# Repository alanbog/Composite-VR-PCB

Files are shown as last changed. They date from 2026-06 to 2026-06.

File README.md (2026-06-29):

# Composite-VR-PCB

This repository contains the hardware design of a controller board for CRT-based VR headset. The circuit contains an AMD Spartan 7 FPGA which splits the incoming HDMI video into separate luma only (black-and-white) NTSC composite video signals for the left and right eye. It also contains an RP2040 microcontroller which serves two purposes:

1. Act as a JTAG programmer for the FPGA using [xvc-pico](https://github.com/kholia/xvc-pico)
2. Transmit 3-DOF tracking data back to a PC using the on-board IMU (based on [Relativty](https://github.com/relativty/Relativty)).

The board also contains a USB hub and a USB C port intended to be connected to a Vive Tracker. When a Vive tracker is connected and SteamVR settings are configured to use the Vive Tracker to [override the default tracking](https://github.com/ValveSoftware/openvr/wiki/TrackingOverrides), the onboard IMU  tracking will not be used, and the RP2040 will only serve to let SteamVR know that the headset is connected. 

The board is the same dimensions and has the same mounting hole placement as a Raspberry Pi Zero.

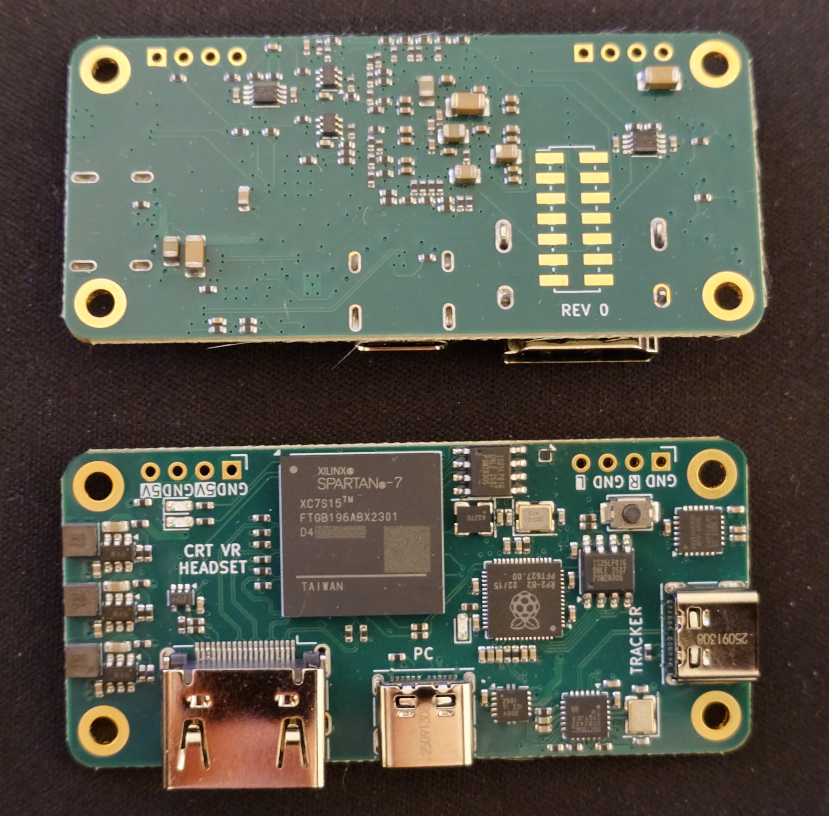
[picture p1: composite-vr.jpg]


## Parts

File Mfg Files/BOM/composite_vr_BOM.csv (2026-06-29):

Reference | Qty | Value | Tolerance | Rating | DNP | Footprint | Mfg | Mfg PN | JLCPCB
C1,C2,C7,C8,C9,C10,C11,C14,C15,C16,C17,C19,C21,C24,C25,C27,C29,C30,C34,C42,C56,C58,C59,C70 | 24 | 100n | 10% | 16V |  | PCM_JLCPCB:C_0402 | Samsung Electro-Mechanics | CL05B104KO5NNNC | C1525
C3,C5,C28,C33 | 4 | 15p | 5% | 50V |  | PCM_JLCPCB:C_0402 | FH (Guangdong Fenghua Advanced Tech) | 0402CG150J500NT | C1548
C4,C13,C20,C67 | 4 | 10u | 10% | 10V |  | PCM_JLCPCB:C_0603 | Samsung Electro-Mechanics | CL10A106KP8NNNC | C19702
C6 | 1 | 2.2n | 10% | 50V |  | PCM_JLCPCB:C_0402 | FH (Guangdong Fenghua Advanced Tech) | 0402B222K500NT | C1531
C12,C18,C26,C36,C39,C43,C44,C49,C51,C52 | 10 | 4u7 | 20% | 10V |  | PCM_JLCPCB:C_0402 | Samsung Electro-Mechanics | CL05A475MP5NRNC | C23733
C22,C23,C31,C32 | 4 | 1u | 10% | 25V |  | PCM_JLCPCB:C_0402 | Samsung Electro-Mechanics | CL05A105KA5NQNC | C52923
C35,C40,C41 | 3 | 100n | 10% | 16V | DNP | PCM_JLCPCB:C_0402 | Samsung Electro-Mechanics | CL05B104KO5NNNC | C1525
C37,C45,C69 | 3 | 100u | 20% | 6.3V |  | PCM_JLCPCB:C_1206 | Samsung Electro-Mechanics | CL31A107MQHNNNE | C15008
C38,C53,C61,C65,C68 | 5 | 47u | 20% | 6.3V |  | PCM_JLCPCB:C_0805 | Samsung Electro-Mechanics | CL21A476MQYNNNE | C16780
C46,C47,C48,C50,C54,C55,C57,C60,C62,C63,C64,C66 | 12 | 470n | 10% | 10V |  | PCM_JLCPCB:C_0402 | Samsung Electro-Mechanics | CL05A474KP5NNNC | C47339
D1,D2,D3 | 3 | Red LED |  |  |  | LED_SMD:LED_0603_1608Metric | Hubei KENTO Elec | KT-0603R | C2286
J1,J2 | 2 | Conn_01x04 |  |  | DNP | Connector_PinHeader_2.54mm:PinHeader_1x04_P2.54mm_Vertical |  |  | -
J3,J5 | 2 | USB_C_Receptacle |  |  |  | Connector_USB:USB_C_Receptacle_Molex_105450-0101 | MOLEX | 1054500101 | C134092
J4 | 1 | HDMI_A |  |  |  | Connector_Video:HDMI_A_Molex_208658-1001_Horizontal | XUNPU | HDMI-001S | C720616
J6 | 1 | Conn_02x07_Odd_Even |  |  | DNP | Connector_PinHeader_2.00mm:PinHeader_2x07_P2.00mm_Vertical_SMD
L1,L2,L3 | 3 | 2u2 |  |  |  | Inductor_SMD:L_Taiyo-Yuden_MD-3030 | Murata Electronics | LQH3NPN2R2MJRL | C341775
R1,R5,R15,R23,R26,R27,R64,R66,R76,R80 | 10 | 0 | 1% | 62.5mW |  | PCM_JLCPCB:R_0402 | UNI-ROYAL(Uniroyal Elec) | 0402WGF0000TCE | C17168
R2,R4,R19,R20,R22 | 5 | 2.2K | 1% | 62.5mW |  | PCM_JLCPCB:R_0402 | UNI-ROYAL(Uniroyal Elec) | 0402WGF2201TCE | C25879
R3,R7,R9,R13,R14,R16,R24,R25 | 8 | 49.9 | 1% | 62.5mW |  | PCM_JLCPCB:R_0402 | UNI-ROYAL(Uniroyal Elec) | 0402WGF499JTCE | C25120
R6,R78 | 2 | 10K | 1% | 62.5mW |  | PCM_JLCPCB:R_0402 | UNI-ROYAL(Uniroyal Elec) | 0402WGF1002TCE | C25744
R8,R12,R21 | 3 | 1K | 1% | 62.5mW |  | PCM_JLCPCB:R_0402 | UNI-ROYAL(Uniroyal Elec) | 0402WGF1001TCE | C11702
R10,R34 | 2 | 33K | 1% | 62.5mW |  | PCM_JLCPCB:R_0402 | UNI-ROYAL(Uniroyal Elec) | 0402WGF3302TCE | C25779
R11,R31,R32,R94 | 4 | 22K | 1% | 62.5mW |  | PCM_JLCPCB:R_0402 | UNI-ROYAL(Uniroyal Elec) | 0402WGF2202TCE | C25768
R17,R33,R35,R36,R37,R100,R101,R102 | 8 | 100K | 1% | 62.5mW |  | PCM_JLCPCB:R_0402 | UNI-ROYAL(Uniroyal Elec) | 0402WGF1003TCE | C25741
R18,R74,R93 | 3 | 200K | 1% | 62.5mW |  | PCM_JLCPCB:R_0402 | UNI-ROYAL(Uniroyal Elec) | 0402WGF2003TCE | C25764
R28,R98 | 2 | 5.1K | 1% | 62.5mW |  | PCM_JLCPCB:R_0402 | UNI-ROYAL(Uniroyal Elec) | 0402WGF5101TCE | C25905
R29,R30 | 2 | 22 | 1% | 62.5mW |  | PCM_JLCPCB:R_0402 | UNI-ROYAL(Uniroyal Elec) | 0402WGF220JTCE | C25092
R38,R39,R40,R41,R51,R58,R62,R72,R81,R83,R89,R90,R91,R92 | 14 | 7.5K | 0.1% | 62.5mW |  | PCM_JLCPCB:R_0402 | UNI-ROYAL(Uniroyal Elec) | TC0225B7501TCC | C28566374
R42,R45,R46,R47,R48,R50,R53,R59,R63,R75,R79,R82,R84,R85,R86,R87,R88,R97 | 18 | 15K | 0.1% | 62.5mW |  | PCM_JLCPCB:R_0402 | FH (Guangdong Fenghua Advanced Tech) | TC02G1502BT | C20627044
R43,R44,R49,R67,R68,R69,R70,R77,R96 | 9 | 4.7K | 1% | 62.5mW |  | PCM_JLCPCB:R_0402 | UNI-ROYAL(Uniroyal Elec) | 0402WGF4701TCE | C25900
R52,R65 | 2 | 75 | 1% | 62.5mW |  | PCM_JLCPCB:R_0402 | UNI-ROYAL(Uniroyal Elec) | 0402WGF750JTCE | C25133
R54,R55 | 2 | 4.7K | 1% | 62.5mW | DNP | PCM_JLCPCB:R_0402 | UNI-ROYAL(Uniroyal Elec) | 0402WGF4701TCE | C25900
R56,R57 | 2 | 75 | 1% | 62.5mW | DNP | PCM_JLCPCB:R_0402 | UNI-ROYAL(Uniroyal Elec) | 0402WGF750JTCE | C25133
R60,R71 | 2 | 8.2K | 1% | 62.5mW |  | PCM_JLCPCB:R_0402 | UNI-ROYAL(Uniroyal Elec) | 0402WGF8201TCE | C25924
R61,R73 | 2 | 18K | 1% | 62.5mW |  | PCM_JLCPCB:R_0402 | UNI-ROYAL(Uniroyal Elec) | 0402WGF1802TCE | C25762
R95 | 1 | 330 | 1% | 62.5mW |  | PCM_JLCPCB:R_0402 | UNI-ROYAL(Uniroyal Elec) | 0402WGF3300TCE | C25104
R99 | 1 | 12K | 1% | 62.5mW |  | PCM_JLCPCB:R_0402 | UNI-ROYAL(Uniroyal Elec) | 0402WGF1202TCE | C25752
SW1 | 1 | SW_Push |  |  |  | Button_Switch_SMD:SW_SPST_TS-1088-xR025 | XUNPU | TS-1088-AR02016 | C720477
U1 | 1 | AK09918C |  |  | DNP | Package_BGA:WLP-4_0.83x0.83mm_P0.4mm | Asahi Kasei Microdevices | AK09918C | C2655004
U2,U6 | 2 | IS25LP016D |  |  |  | Package_SO:SO-8_3.9x4.9mm_P1.27mm | ISSI(Integrated Silicon Solution) | IS25LP016D-JNLE-TR | C2653501
U3 | 1 | xc7s15ftgb196 |  |  |  | Package_BGA:Xilinx_FTGB196 | AMD/XILINX | XC7S15-2FTGB196I | C1521865
U4 | 1 | MPU-6050 |  |  |  | Sensor_Motion:InvenSense_QFN-24_4x4mm_P0.5mm | TDK InvenSense | MPU-6050 | C24112
U5,U9,U10 | 3 | TLV62568PDDCR |  |  |  | Library:SOT-23-6-small_courtyard | Texas Instruments | TLV62568PDDCR | C398369
U7 | 1 | NC7SZ125P5X |  |  |  | Package_TO_SOT_SMD:SOT-353_SC-70-5 | onsemi | NC7SZ125P5X | C112084
U8 | 1 | RP2040 |  |  |  | Package_DFN_QFN:QFN-56-1EP_7x7mm_P0.4mm_EP3.2x3.2mm | Raspberry Pi | RP2040 | C2040
U11 | 1 | TPS2561 |  |  |  | Package_SON:VSON-10-1EP_3x3mm_P0.5mm_EP1.65x2.4mm_ThermalVias | Texas Instruments | TPS2561DRCR | C140303
U12 | 1 | USB2422 |  |  |  | Package_DFN_QFN:QFN-24-1EP_4x4mm_P0.5mm_EP2.5x2.5mm | Microchip Tech | USB2422T/MJ | C622611
U13,U15 | 2 | OPA358 |  |  |  | Package_TO_SOT_SMD:SOT-363_SC-70-6 | Texas Instruments | OPA358AIDCKT | C2057755
U14 | 1 | TXS0102DCU |  |  | DNP | Package_SO:VSSOP-8_2.3x2mm_P0.5mm | Texas Instruments | TXS0102DCUR | C53434
U16 | 1 | TXS0102DCU |  |  |  | Package_SO:VSSOP-8_2.3x2mm_P0.5mm | Texas Instruments | TXS0102DCUR | C53434
Y1 | 1 | 50MHz |  |  |  | Oscillator:Oscillator_SMD_SiT_PQFN-4Pin_3.2x2.5mm | SiTime | SiT8008BI-22-33E-50.000000 | C26267
Y2 | 1 | 12MHz |  |  |  | Crystal:Crystal_SMD_3225-4Pin_3.2x2.5mm | SJK(SHENZHEN CRYSTAL TECH) | 7U12000E09UCG | C524716
Y3 | 1 | 24MHz |  |  |  | Crystal:Crystal_SMD_3225-4Pin_3.2x2.5mm | SJK(SHENZHEN CRYSTAL TECH) | 7U24000E09UCG | C251611

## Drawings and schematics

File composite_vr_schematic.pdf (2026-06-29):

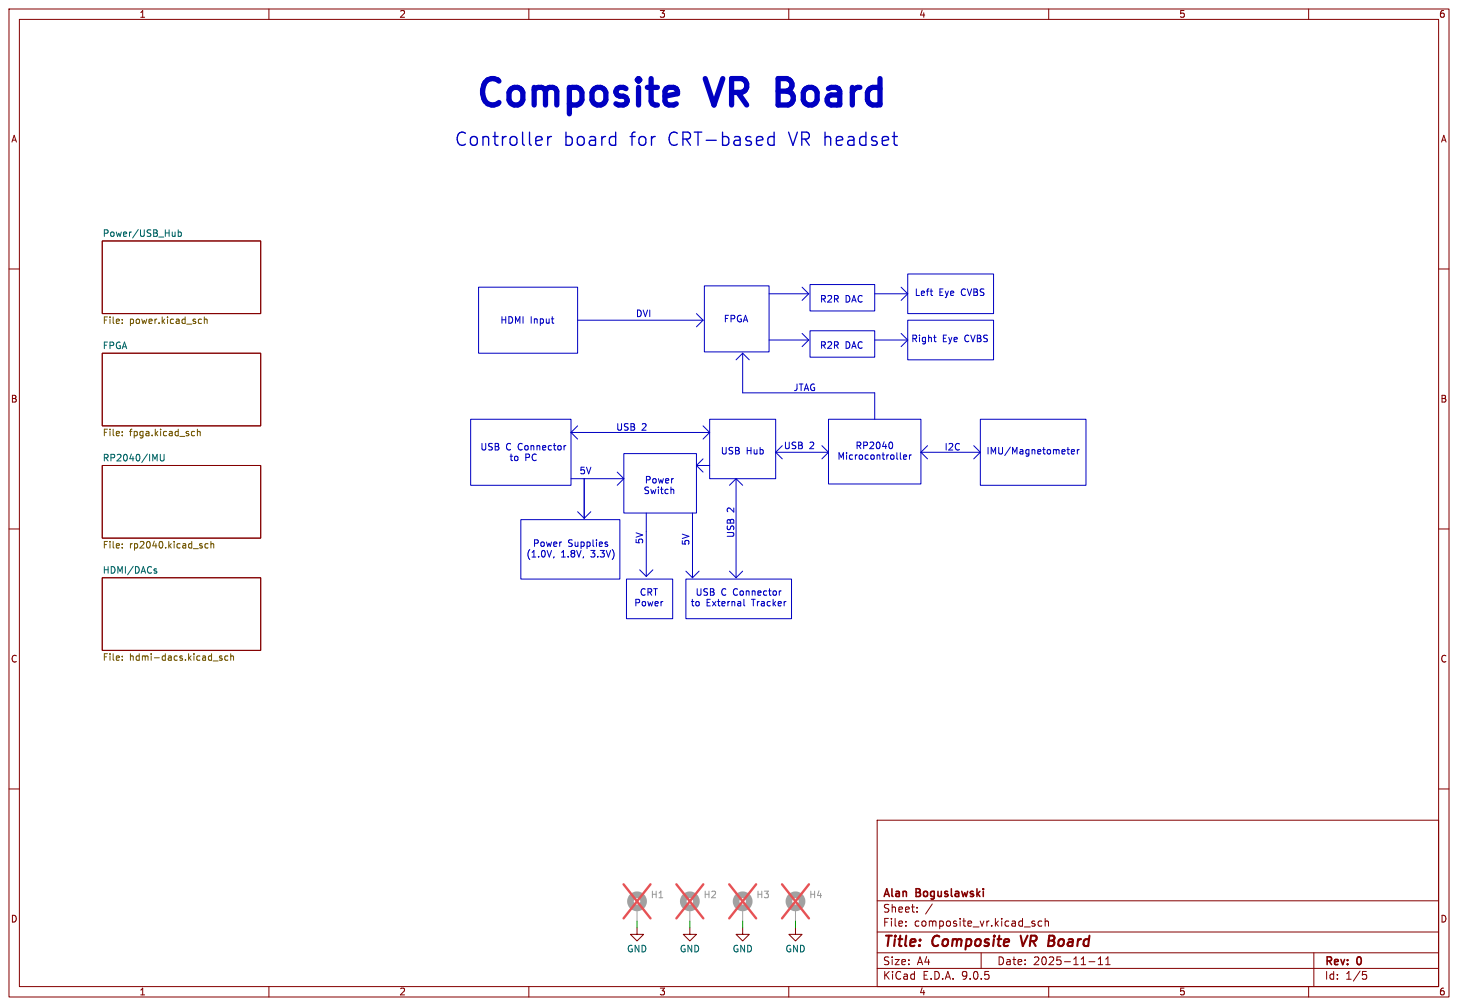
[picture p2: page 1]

Id: 1/5 Title: Composite VR Board

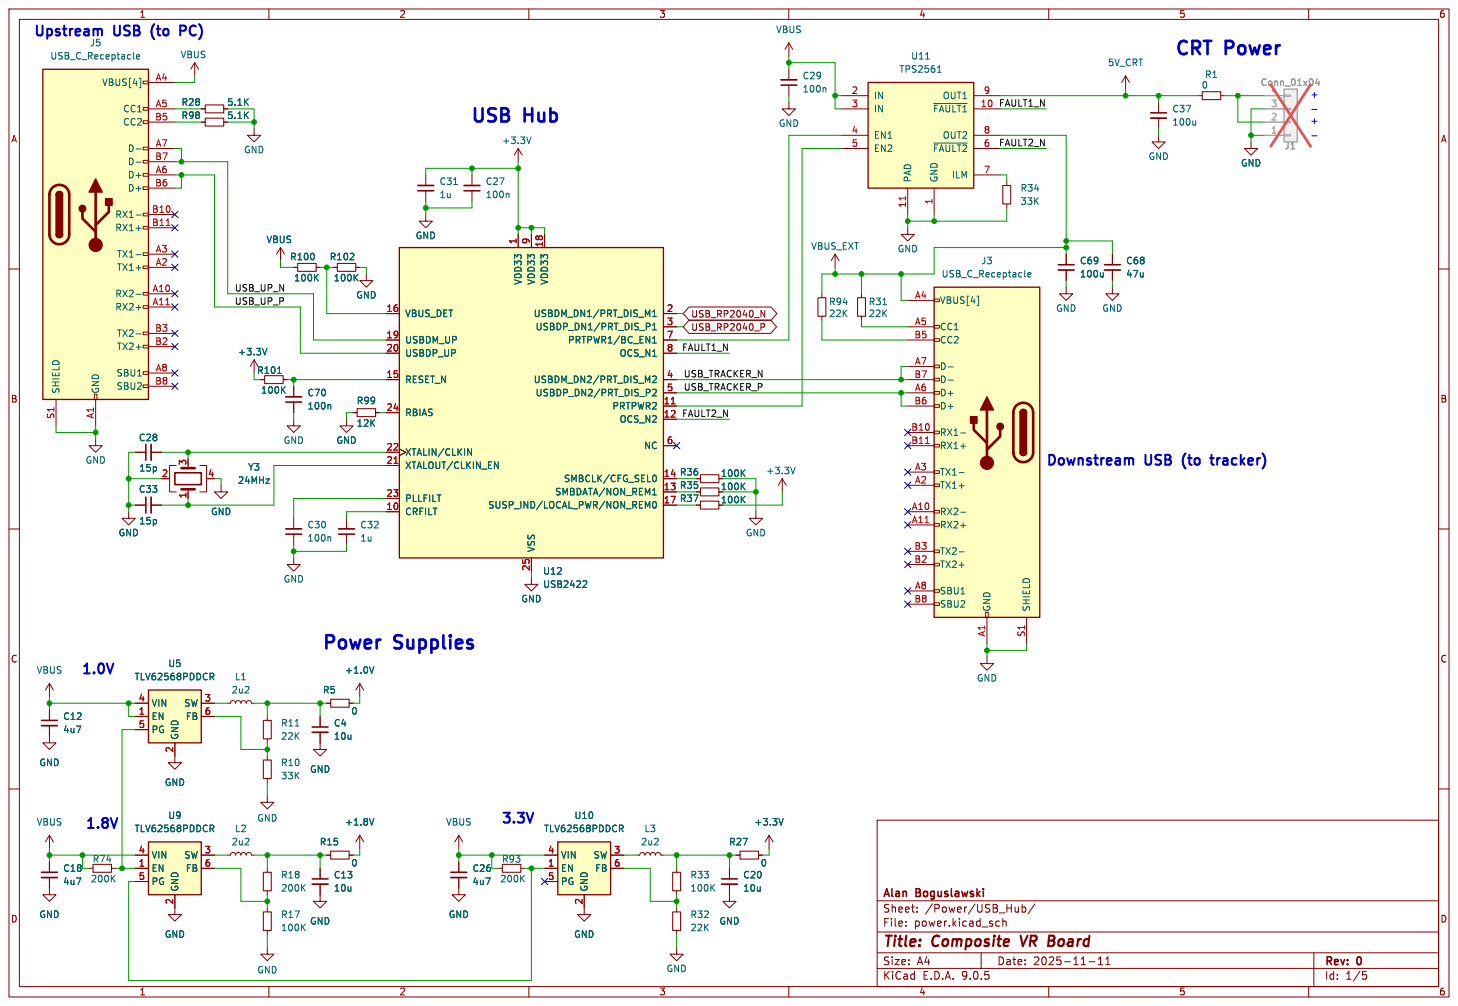
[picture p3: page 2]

Upstream USB (to PC)

9 VSS 25 VDD33 18 USBDM_DN1/PRT_DIS_M1 2 USBDP_DN1/PRT_DIS_P1 3 PRTPWR1/BC_EN1 7 OCS_N1 8 USBDM_DN2/PRT_DIS_M2 4 USBDP_DN2/PRT_DIS_P2 5 PRTPWR2 11 OCS_N2 12 NC 6 SMBCLK/CFG_SEL0 14 SMBDATA/NON_REM1 13 SUSP_IND/LOCAL_PWR/NON_REM0 17 U12 USB2422 C31

9 VSS 25 VDD33 18 USBDM_DN1/PRT_DIS_M1 2 USBDP_DN1/PRT_DIS_P1 3 PRTPWR1/BC_EN1 7 OCS_N1 8 USBDM_DN2/PRT_DIS_M2 4 USBDP_DN2/PRT_DIS_P2 5 PRTPWR2 11 OCS_N2 12 NC 6 SMBCLK/CFG_SEL0 14 SMBDATA/NON_REM1 13 SUSP_IND/LOCAL_PWR/NON_REM0 17 GND

Downstream USB (to tracker)

2 SW 3 FB 6 GND GND

Id: 1/5 Title: Composite VR Board

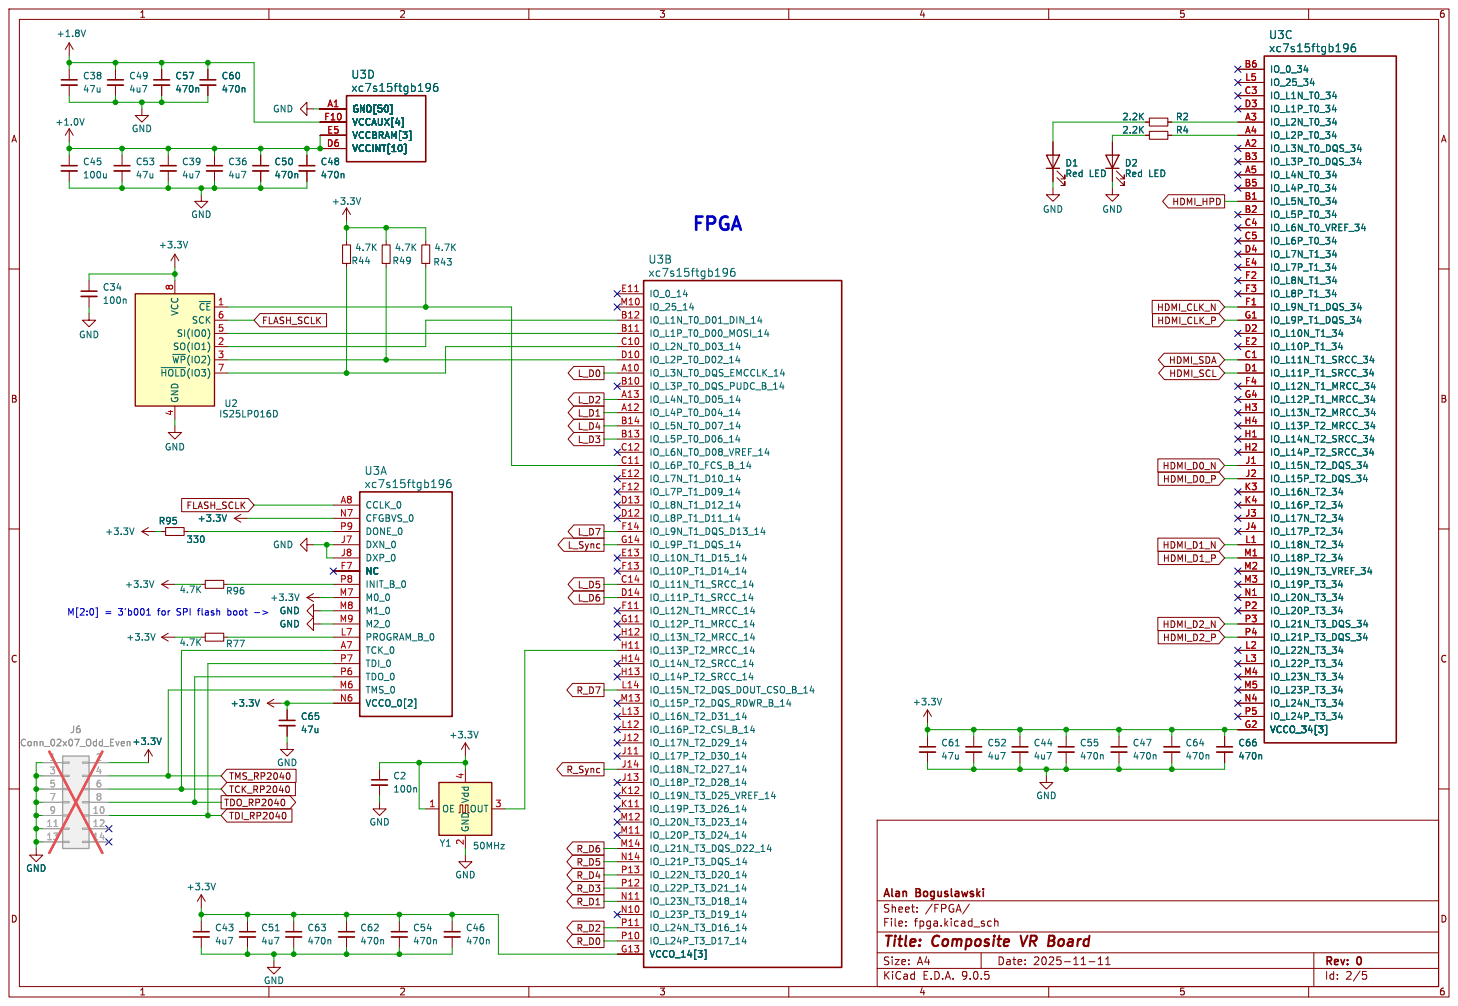
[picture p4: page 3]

8 GND
~{CE}1 SCK 6 SI(IO0) 5 SO(IO1) 2 ~{WP}(IO2)3 ~{HOLD}(IO3)7 VCC

Id: 2/5 Title: Composite VR Board

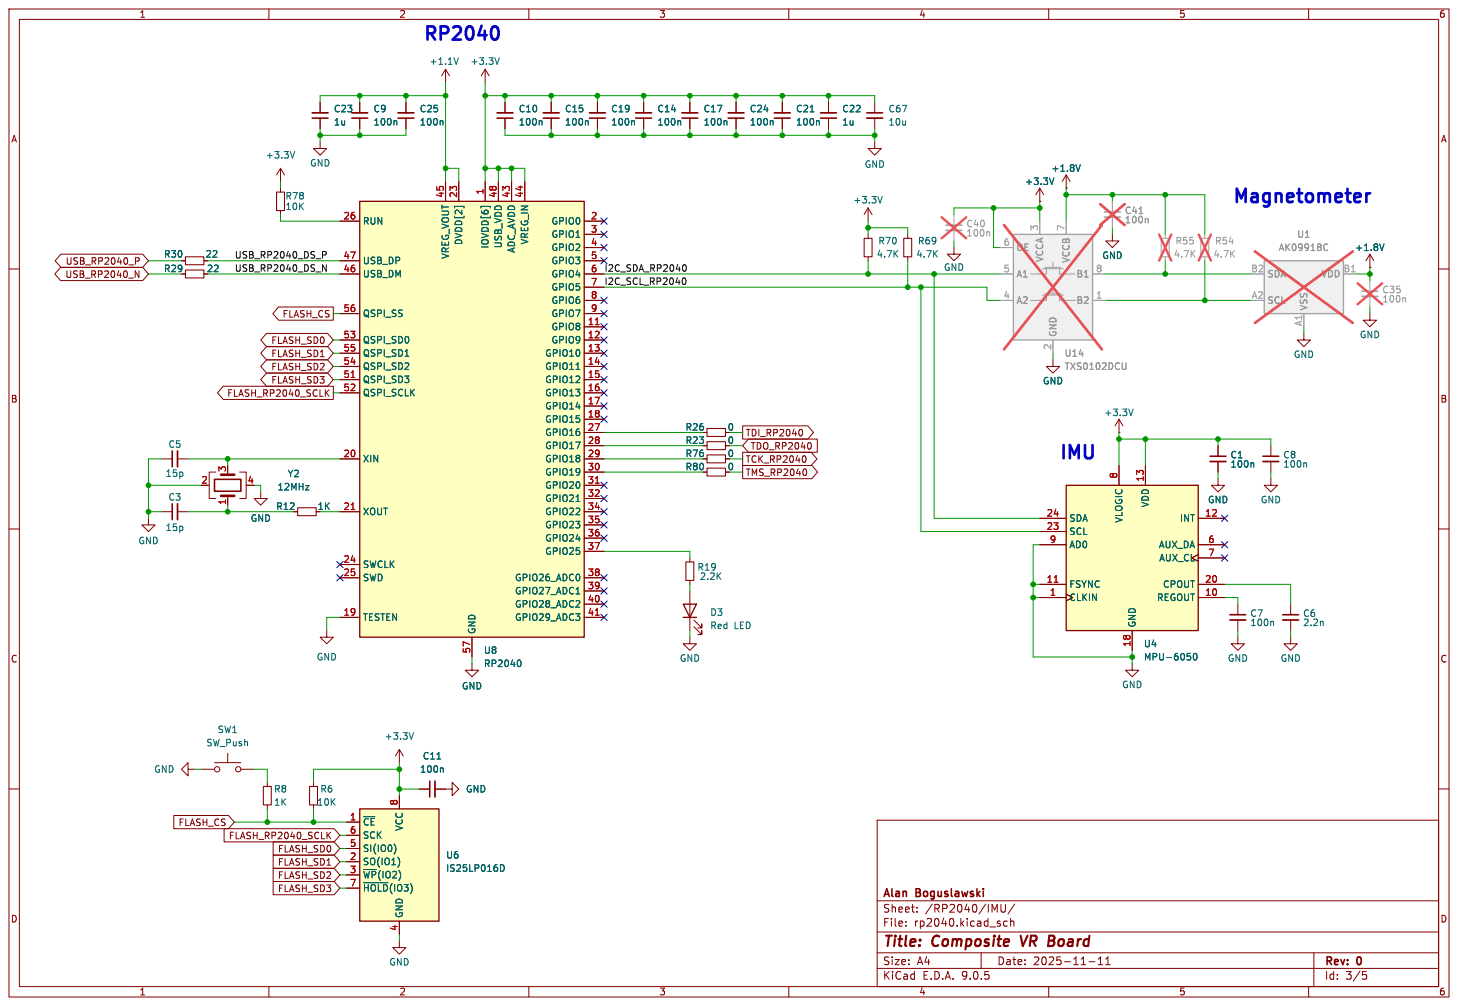
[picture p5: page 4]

Id: 3/5 Title: Composite VR Board

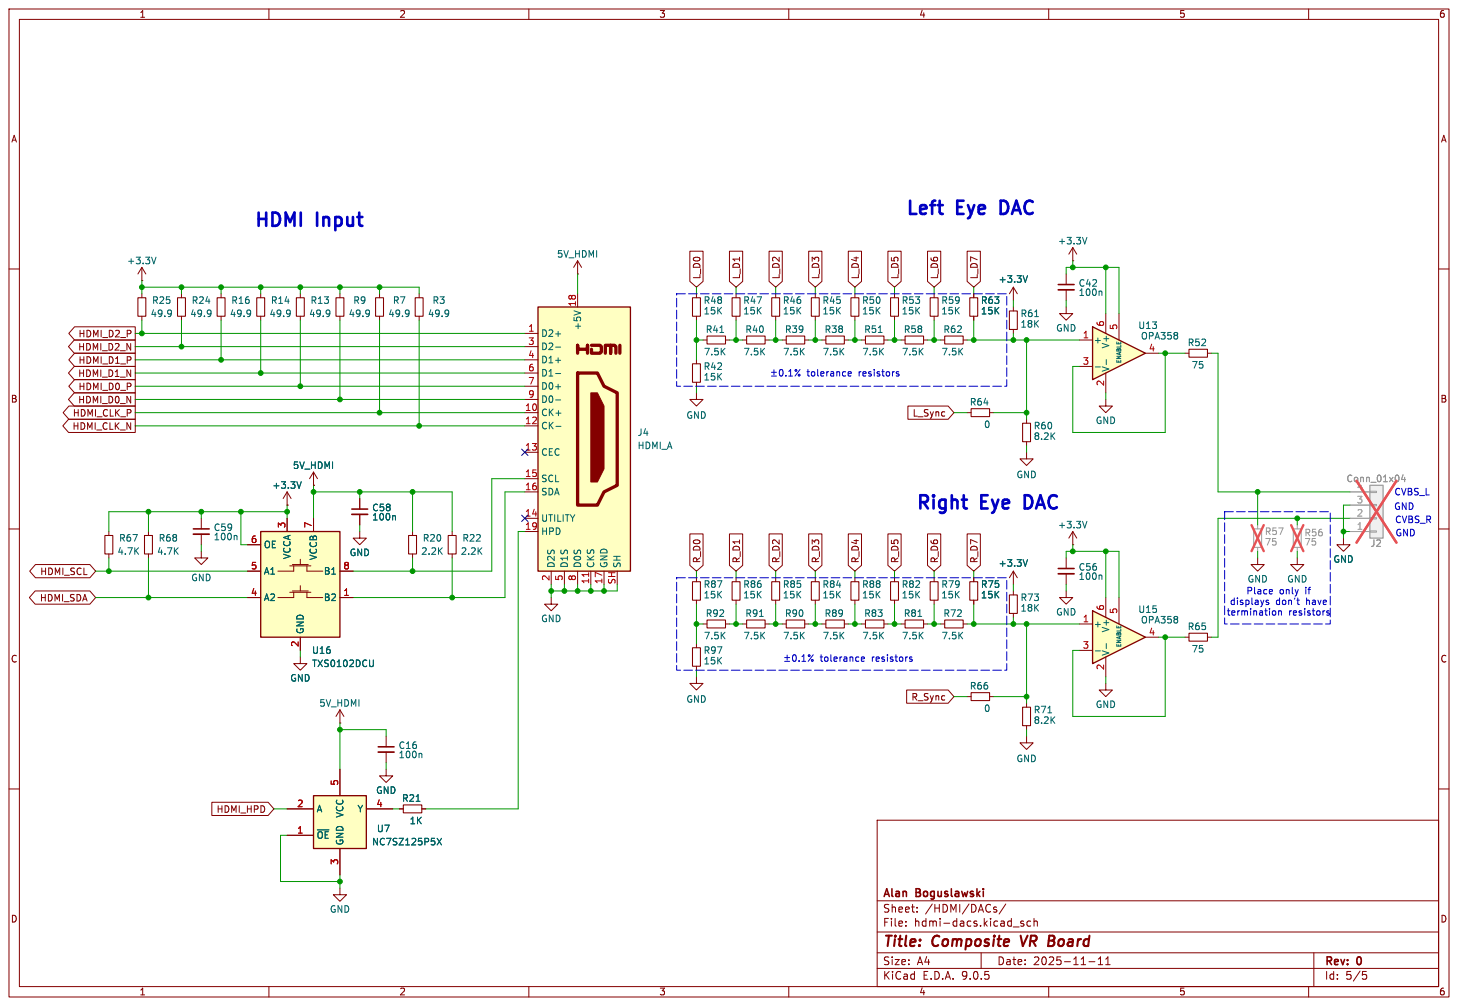
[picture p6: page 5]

8 CKS 11 GND 17 SH SH

Id: 5/5 Title: Composite VR Board

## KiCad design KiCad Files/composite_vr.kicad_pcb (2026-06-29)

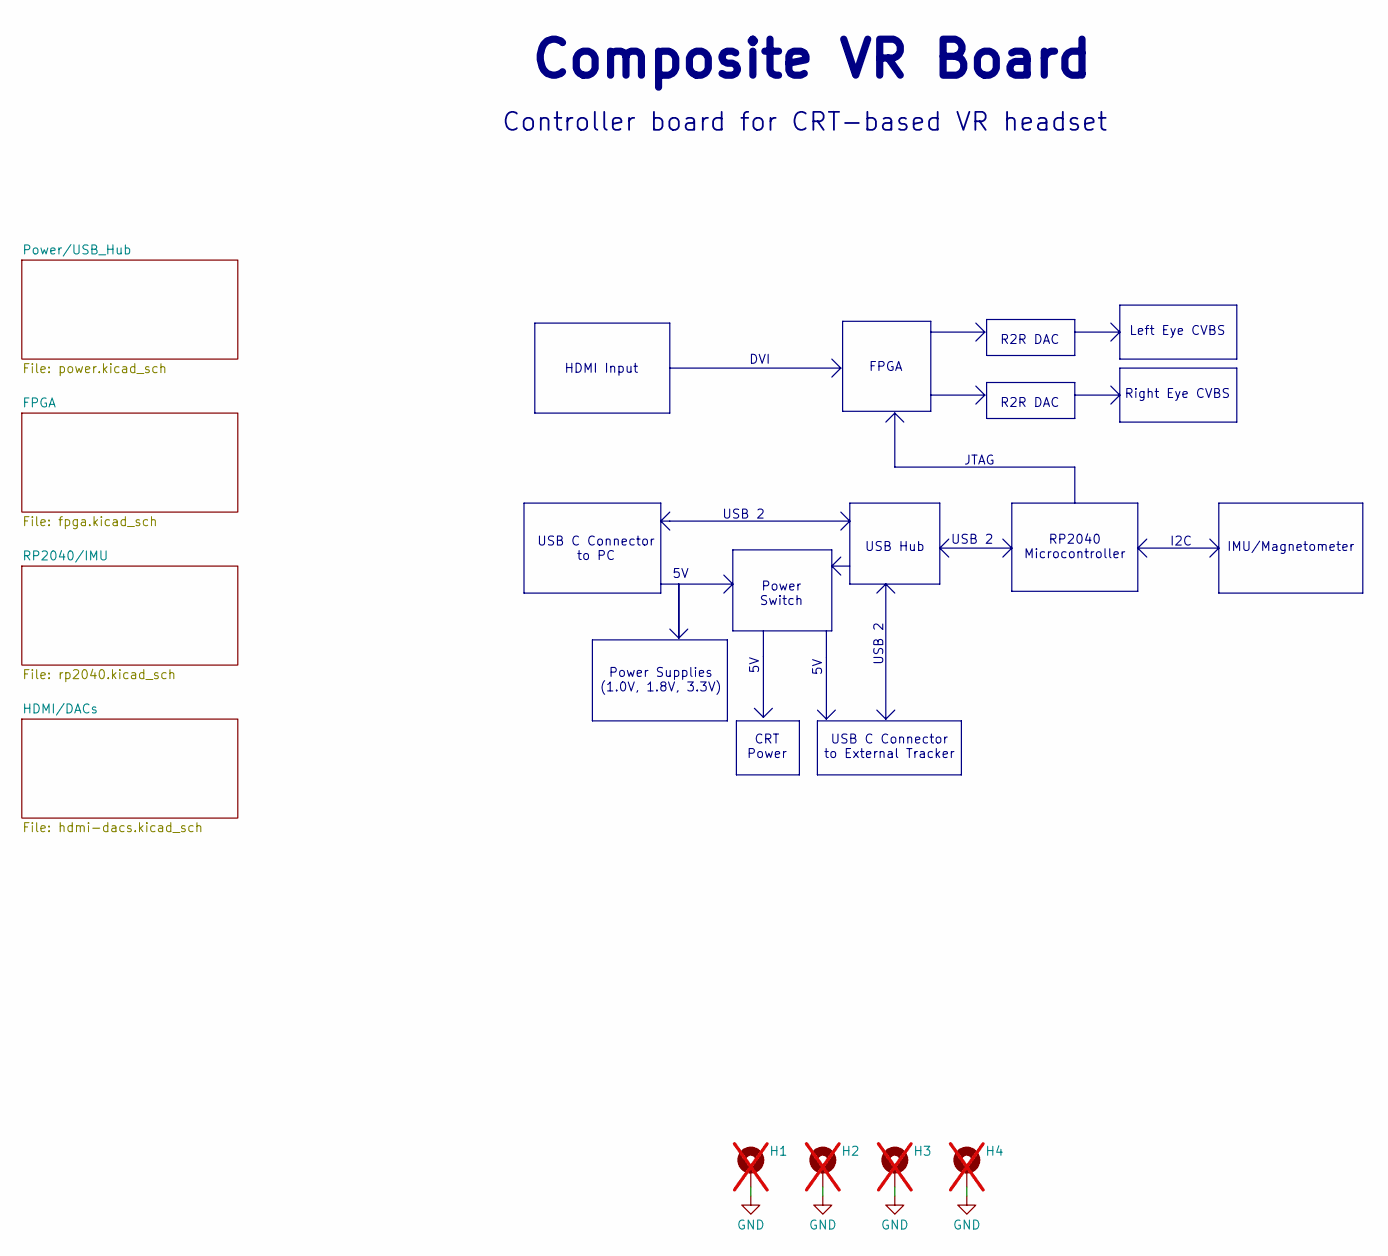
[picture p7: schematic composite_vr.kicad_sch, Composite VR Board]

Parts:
H1, H2, H3, H4: MountingHole_Pad; MountingHole_2.7mm_M2.5_DIN965_Pad; not fitted

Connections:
GND: H1.1, H2.1, H3.1, H4.1; also elsewhere on the board

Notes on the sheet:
USB 2
USB C Connector to External Tracker
Controller board for CRT-based VR headset
R2R DAC
FPGA
CRT Power
USB C Connector to PC
IMU/Magnetometer
Left Eye CVBS
USB Hub
Power Switch
Power Supplies (1.0V, 1.8V, 3.3V)
I2C
RP2040 Microcontroller
Right Eye CVBS
Composite VR Board
HDMI Input
DVI
JTAG

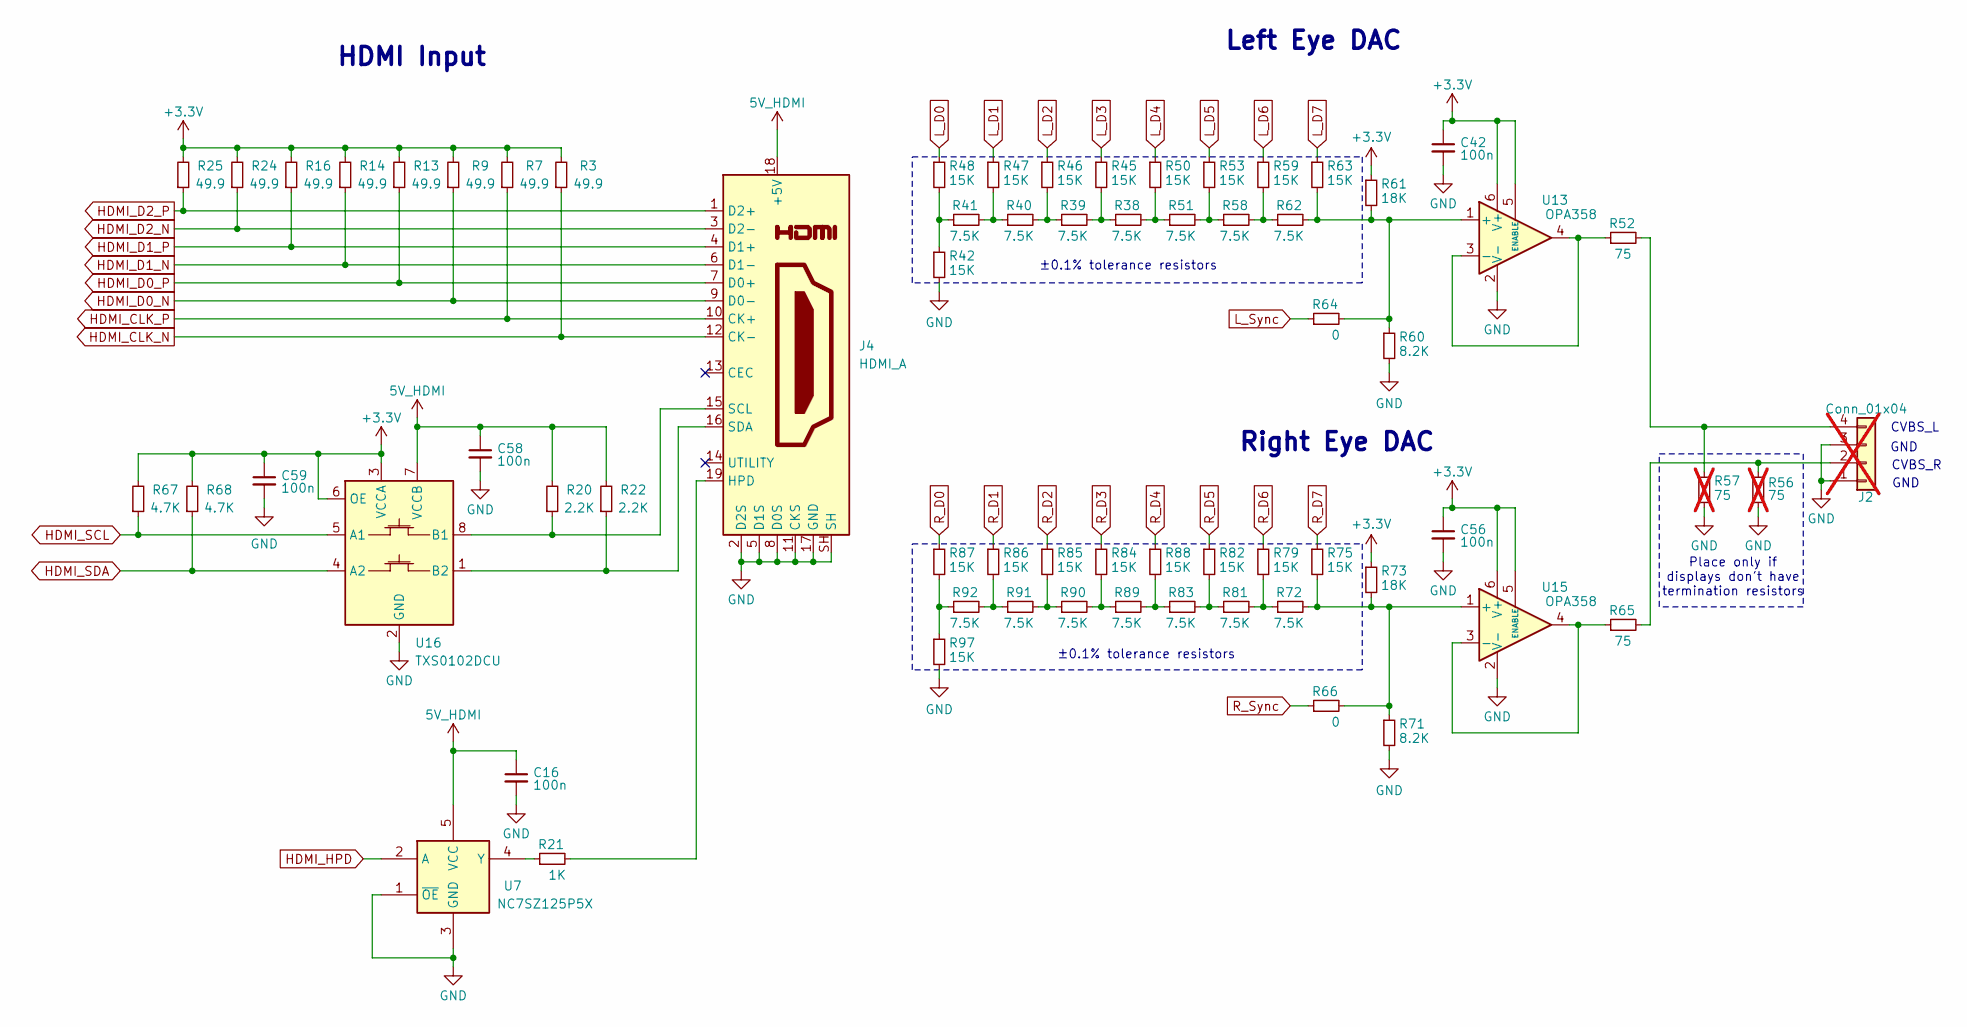
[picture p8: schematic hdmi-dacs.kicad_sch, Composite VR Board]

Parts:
C16, C42, C56, C58, C59: 100n; C_0402; Rating 16V; Tolerance 10%; Mfg PN CL05B104KO5NNNC; JLCPCB C1525
J2: Conn_01x04; PinHeader_1x04_P2.54mm_Vertical; not fitted
J4: HDMI_A; HDMI_A_Molex_208658-1001_Horizontal; Mfg PN HDMI-001S; JLCPCB C720616
R3, R7, R9, R13, R14, R16, R24, R25: 49.9; R_0402; Rating 62.5mW; Tolerance 1%; Mfg PN 0402WGF499JTCE; JLCPCB C25120
R20, R22: 2.2K; R_0402; Rating 62.5mW; Tolerance 1%; Mfg PN 0402WGF2201TCE; JLCPCB C25879
R21: 1K; R_0402; Rating 62.5mW; Tolerance 1%; Mfg PN 0402WGF1001TCE; JLCPCB C11702
R38, R39, R40, R41, R51, R58, R62, R72, R81, R83, R89, R90, R91, R92: 7.5K; R_0402; Rating 62.5mW; Tolerance 0.1%; Mfg PN TC0225B7501TCC; JLCPCB C28566374
R42, R45, R46, R47, R48, R50, R53, R59, R63, R75, R79, R82, R84, R85, R86, R87, R88, R97: 15K; R_0402; Rating 62.5mW; Tolerance 0.1%; Mfg PN TC02G1502BT; JLCPCB C20627044
R52, R65: 75; R_0402; Rating 62.5mW; Tolerance 1%; Mfg PN 0402WGF750JTCE; JLCPCB C25133
R56, R57: 75; R_0402; Rating 62.5mW; Tolerance 1%; Mfg PN 0402WGF750JTCE; JLCPCB C25133; not fitted
R60, R71: 8.2K; R_0402; Rating 62.5mW; Tolerance 1%; Mfg PN 0402WGF8201TCE; JLCPCB C25924
R61, R73: 18K; R_0402; Rating 62.5mW; Tolerance 1%; Mfg PN 0402WGF1802TCE; JLCPCB C25762
R64, R66: 0; R_0402; Rating 62.5mW; Tolerance 1%; Mfg PN 0402WGF0000TCE; JLCPCB C17168
R67, R68: 4.7K; R_0402; Rating 62.5mW; Tolerance 1%; Mfg PN 0402WGF4701TCE; JLCPCB C25900
U7: NC7SZ125P5X; SOT-353_SC-70-5; Mfg PN NC7SZ125P5X; JLCPCB C112084
U13, U15: OPA358; SOT-363_SC-70-6; Mfg PN OPA358AIDCKT; JLCPCB C2057755
U16: TXS0102DCU; VSSOP-8_2.3x2mm_P0.5mm; Mfg PN TXS0102DCUR; JLCPCB C53434

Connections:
5V_HDMI: C16.1, C58.1, J4.18 (+5V), R20.2, R22.2, U7.5 (VCC), U16.7 (VCCB)
+3.3V: C42.1, C56.1, C59.1, R3.2, R7.2, R9.2, R13.2, R14.2, R16.2, R24.2, R25.2, R61.1, R67.2, R68.2, R73.1, U13.5 (ENABLE), U13.6 (V+), U15.5 (ENABLE), U15.6 (V+), U16.3 (VCCA), U16.6 (OE); also elsewhere on the board
GND: C16.2, C42.2, C56.2, C58.2, C59.2, J2.1, J2.3, J4.2 (D2S), J4.5 (D1S), J4.8 (D0S), J4.11 (CKS), J4.17 (GND), J4.SH, R42.2, R56.2, R57.2, R60.2, R71.2, R97.2, U7.1 (~OE), U7.3 (GND), U13.2 (V-), U15.2 (V-), U16.2 (GND); also elsewhere on the board
HDMI_CLK_N: J4.12 (CK-), R3.1; also elsewhere on the board
HDMI_CLK_P: J4.10 (CK+), R7.1; also elsewhere on the board
HDMI_D0_N: J4.9 (D0-), R9.1; also elsewhere on the board
HDMI_D0_P: J4.7 (D0+), R13.1; also elsewhere on the board
HDMI_D1_N: J4.6 (D1-), R14.1; also elsewhere on the board
HDMI_D1_P: J4.4 (D1+), R16.1; also elsewhere on the board
HDMI_D2_N: J4.3 (D2-), R24.1; also elsewhere on the board
HDMI_D2_P: J4.1 (D2+), R25.1; also elsewhere on the board
HDMI_HPD: U7.2 (A); also elsewhere on the board
HDMI_SCL: R67.1, U16.5 (A1); also elsewhere on the board
HDMI_SDA: R68.1, U16.4 (A2); also elsewhere on the board
L_D0: R48.1; also elsewhere on the board
L_D1: R47.1; also elsewhere on the board
L_D2: R46.1; also elsewhere on the board
L_D3: R45.1; also elsewhere on the board
L_D4: R50.1; also elsewhere on the board
L_D5: R53.1; also elsewhere on the board
L_D6: R59.1; also elsewhere on the board
L_D7: R63.1; also elsewhere on the board
L_Sync: R64.1; also elsewhere on the board
unnamed: J2.2, R56.1, R65.2
unnamed: J2.4, R52.2, R57.1
unnamed: J4.19 (HPD), R21.2
unnamed: J4.15 (SCL), R20.1, U16.8 (B1)
unnamed: J4.16 (SDA), R22.1, U16.1 (B2)
unnamed: R38.1, R39.2, R45.2
unnamed: R38.2, R50.2, R51.1
unnamed: R39.1, R40.2, R46.2
unnamed: R40.1, R41.2, R47.2
unnamed: R41.1, R42.1, R48.2
unnamed: R51.2, R53.2, R58.1
unnamed: R58.2, R59.2, R62.1
unnamed: R72.1, R79.2, R81.2
unnamed: R81.1, R82.2, R83.2
unnamed: R83.1, R88.2, R89.2
unnamed: R84.2, R89.1, R90.2
unnamed: R85.2, R90.1, R91.2
unnamed: R86.2, R91.1, R92.2
unnamed: R87.2, R92.1, R97.1
unnamed: R21.1, U7.4 (Y)
unnamed: R60.1, R61.2, R62.2, R63.2, R64.2, U13.1 (+)
unnamed: R52.1, U13.3 (-), U13.4
unnamed: R66.2, R71.1, R72.2, R73.2, R75.2, U15.1 (+)
unnamed: R65.1, U15.3 (-), U15.4
R_D0: R87.1; also elsewhere on the board
R_D1: R86.1; also elsewhere on the board
R_D2: R85.1; also elsewhere on the board
R_D3: R84.1; also elsewhere on the board
R_D4: R88.1; also elsewhere on the board
R_D5: R82.1; also elsewhere on the board
R_D6: R79.1; also elsewhere on the board
R_D7: R75.1; also elsewhere on the board
R_Sync: R66.1; also elsewhere on the board

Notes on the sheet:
CVBS_R
CVBS_L
Right Eye DAC
±0.1% tolerance resistors
Place only if displays don't have termination resistors
GND
Left Eye DAC
HDMI Input

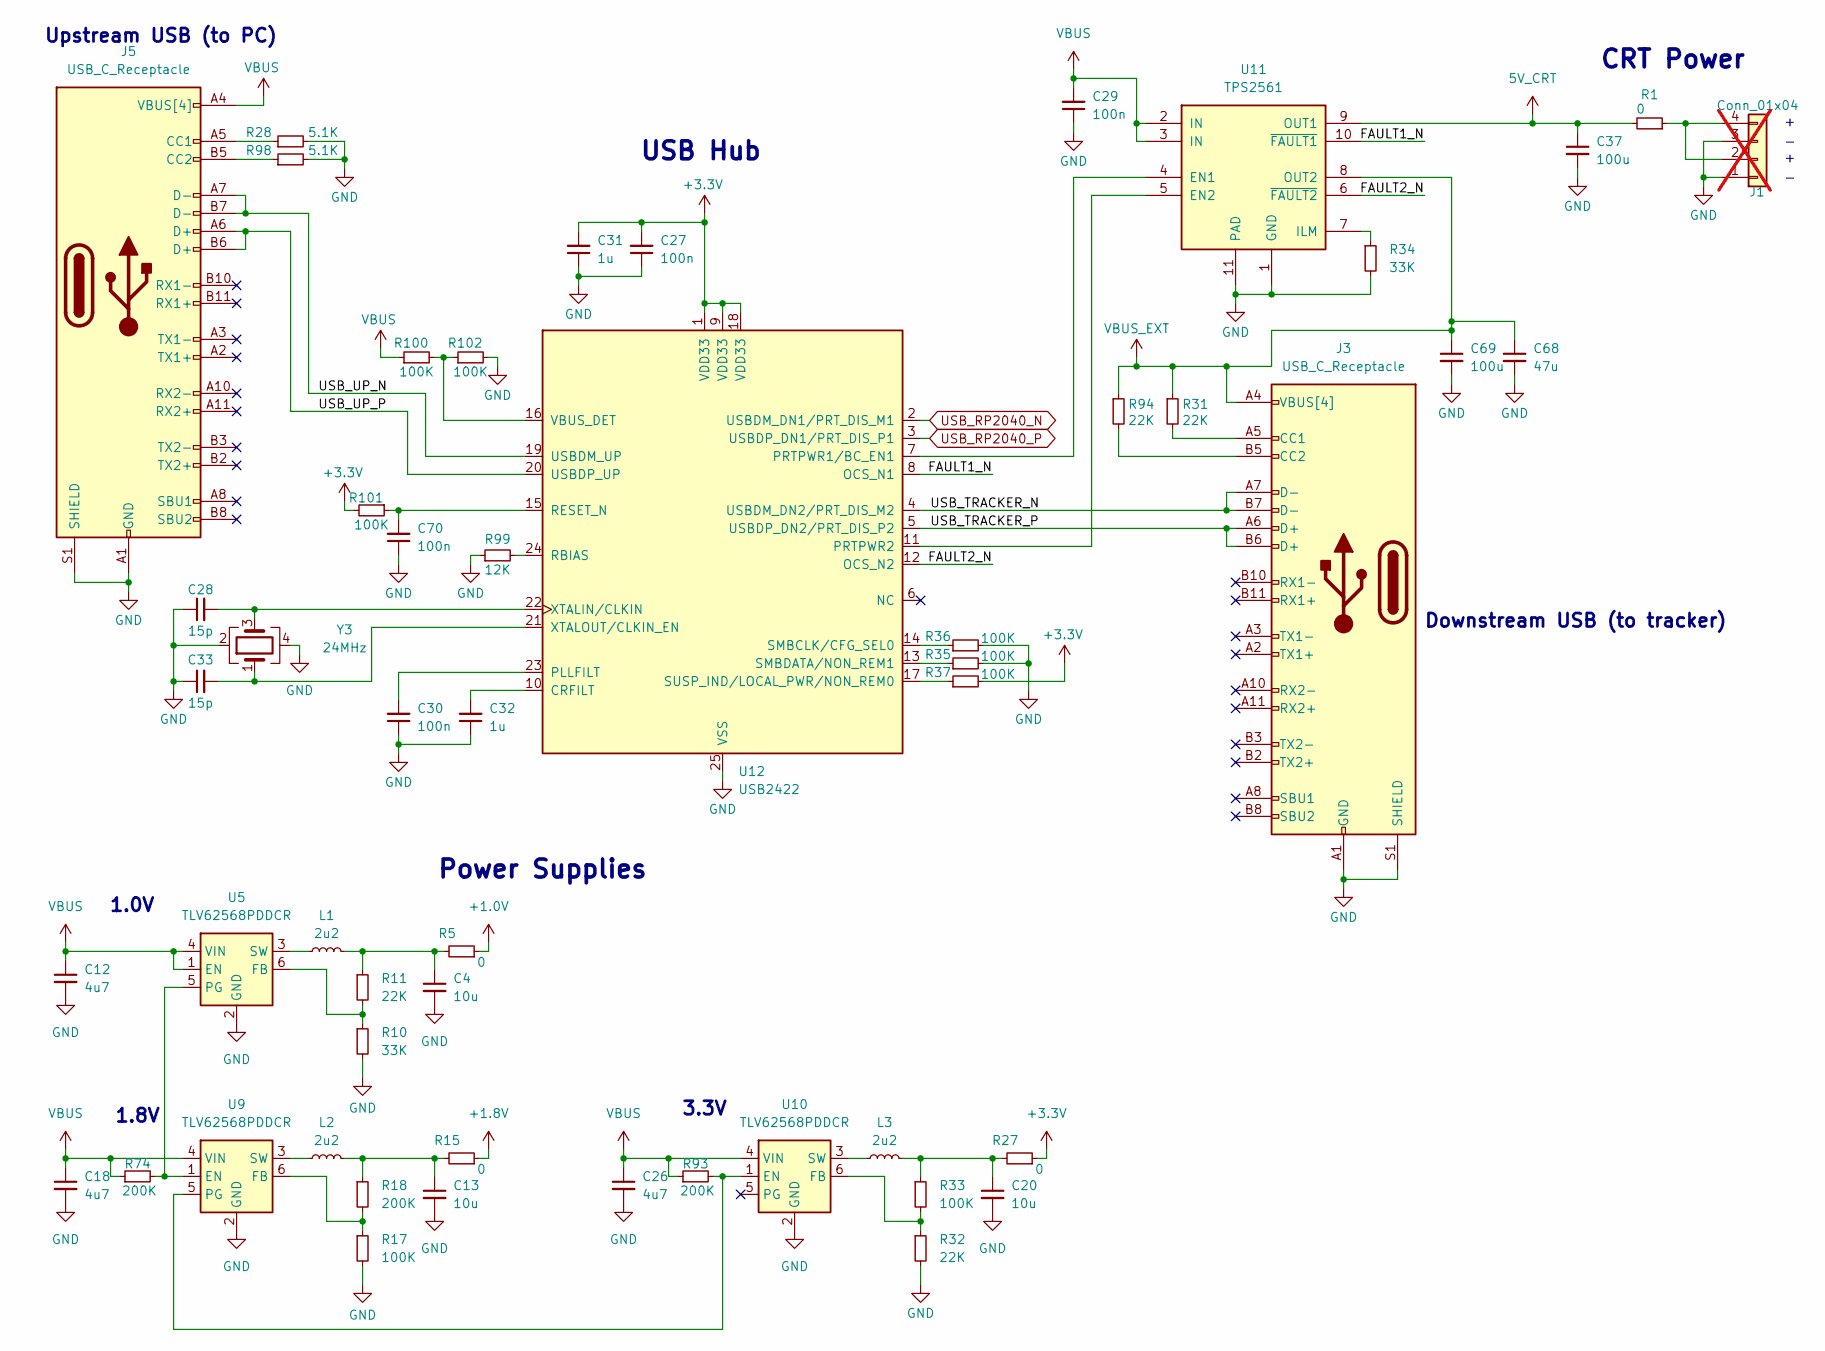
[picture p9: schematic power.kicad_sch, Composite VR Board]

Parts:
C4, C13, C20: 10u; C_0603; Rating 10V; Tolerance 10%; Mfg PN CL10A106KP8NNNC; JLCPCB C19702
C12, C18, C26: 4u7; C_0402; Rating 10V; Tolerance 20%; Mfg PN CL05A475MP5NRNC; JLCPCB C23733
C27, C29, C30, C70: 100n; C_0402; Rating 16V; Tolerance 10%; Mfg PN CL05B104KO5NNNC; JLCPCB C1525
C28, C33: 15p; C_0402; Rating 50V; Tolerance 5%; Mfg PN 0402CG150J500NT; JLCPCB C1548
C31, C32: 1u; C_0402; Rating 25V; Tolerance 10%; Mfg PN CL05A105KA5NQNC; JLCPCB C52923
C37, C69: 100u; C_1206; Rating 6.3V; Tolerance 20%; Mfg PN CL31A107MQHNNNE; JLCPCB C15008
C68: 47u; C_0805; Rating 6.3V; Tolerance 20%; Mfg PN CL21A476MQYNNNE; JLCPCB C16780
J1: Conn_01x04; PinHeader_1x04_P2.54mm_Vertical; not fitted
J3, J5: USB_C_Receptacle; USB_C_Receptacle_Molex_105450-0101; Mfg PN 1054500101; JLCPCB C134092
L1, L2, L3: 2u2; L_Taiyo-Yuden_MD-3030; Mfg PN LQH3NPN2R2MJRL; JLCPCB C341775
R1, R5, R15, R27: 0; R_0402; Rating 62.5mW; Tolerance 1%; Mfg PN 0402WGF0000TCE; JLCPCB C17168
R10, R34: 33K; R_0402; Rating 62.5mW; Tolerance 1%; Mfg PN 0402WGF3302TCE; JLCPCB C25779
R11, R31, R32, R94: 22K; R_0402; Rating 62.5mW; Tolerance 1%; Mfg PN 0402WGF2202TCE; JLCPCB C25768
R17, R33, R35, R36, R37, R100, R101, R102: 100K; R_0402; Rating 62.5mW; Tolerance 1%; Mfg PN 0402WGF1003TCE; JLCPCB C25741
R18, R74, R93: 200K; R_0402; Rating 62.5mW; Tolerance 1%; Mfg PN 0402WGF2003TCE; JLCPCB C25764
R28, R98: 5.1K; R_0402; Rating 62.5mW; Tolerance 1%; Mfg PN 0402WGF5101TCE; JLCPCB C25905
R99: 12K; R_0402; Rating 62.5mW; Tolerance 1%; Mfg PN 0402WGF1202TCE; JLCPCB C25752
U5, U9, U10: TLV62568PDDCR; SOT-23-6-small_courtyard; Mfg PN TLV62568PDDCR; JLCPCB C398369
U11: TPS2561; VSON-10-1EP_3x3mm_P0.5mm_EP1.65x2.4mm_ThermalVias; Mfg PN TPS2561DRCR; JLCPCB C140303
U12: USB2422; QFN-24-1EP_4x4mm_P0.5mm_EP2.5x2.5mm; Mfg PN USB2422T/MJ; JLCPCB C622611
Y3: 24MHz; Crystal_SMD_3225-4Pin_3.2x2.5mm; Mfg PN 7U24000E09UCG; JLCPCB C251611

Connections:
5V_CRT: C37.1, R1.2, U11.9 (OUT1)
+1.0V: R5.1; also elsewhere on the board
+1.8V: R15.1; also elsewhere on the board
+3.3V: C27.2, C31.2, R27.1, R37.2, R101.2, U12.1 (VDD33), U12.9 (VDD33), U12.18 (VDD33); also elsewhere on the board
/Power/USB_Hub/FAULT1_N: U11.10 (~FAULT1), U12.8 (OCS_N1)
/Power/USB_Hub/FAULT2_N: U11.6 (~FAULT2), U12.12 (OCS_N2)
/Power/USB_Hub/USB_TRACKER_N: J3.A7 (D-), J3.B7 (D-), U12.4 (USBDM_DN2/PRT_DIS_M2)
/Power/USB_Hub/USB_TRACKER_P: J3.A6 (D+), J3.B6 (D+), U12.5 (USBDP_DN2/PRT_DIS_P2)
/Power/USB_Hub/USB_UP_N: J5.A7 (D-), J5.B7 (D-), U12.19 (USBDM_UP)
/Power/USB_Hub/USB_UP_P: J5.A6 (D+), J5.B6 (D+), U12.20 (USBDP_UP)
GND: C4.2, C12.2, C13.2, C18.2, C20.2, C26.2, C27.1, C28.1, C29.1, C30.1, C31.1, C32.1, C33.1, C37.2, C68.2, C69.2, C70.1, J1.1, J1.3, J3.A1 (GND), J3.A12 (GND), J3.B1 (GND), J3.B12 (GND), J3.S1 (SHIELD), J5.A1 (GND), J5.A12 (GND), J5.B1 (GND), J5.B12 (GND), J5.S1 (SHIELD), R10.2, R17.2, R28.2, R32.2, R34.2, R35.2, R36.2, R98.2, R99.1, R102.2, U5.2 (GND), U9.2 (GND), U10.2 (GND), U11.1 (GND), U11.11 (PAD), U12.25 (VSS), Y3.2, Y3.4; also elsewhere on the board
unnamed: C4.1, L1.2, R5.2, R11.1
unnamed: C13.1, L2.2, R15.2, R18.1
unnamed: C20.1, L3.2, R27.2, R33.1
unnamed: J1.2, J1.4, R1.1
unnamed: J3.A5 (CC1), R31.2
unnamed: J3.B5 (CC2), R94.2
unnamed: J5.A5 (CC1), R28.1
unnamed: J5.B5 (CC2), R98.1
unnamed: R10.1, R11.2, U5.6 (FB)
unnamed: R74.2, U5.5 (PG), U9.1 (EN)
unnamed: L1.1, U5.3 (SW)
unnamed: R17.1, R18.2, U9.6 (FB)
unnamed: L2.1, U9.3 (SW)
unnamed: R93.2, U9.5 (PG), U10.1 (EN)
unnamed: R32.1, R33.2, U10.6 (FB)
unnamed: L3.1, U10.3 (SW)
unnamed: U11.4 (EN1), U12.7 (PRTPWR1/BC_EN1)
unnamed: U11.5 (EN2), U12.11 (PRTPWR2)
unnamed: R34.1, U11.7 (ILM)
unnamed: C32.2, U12.10 (CRFILT)
unnamed: C30.2, U12.23 (PLLFILT)
unnamed: R99.2, U12.24 (RBIAS)
unnamed: C70.2, R101.1, U12.15 (RESET_N)
unnamed: R36.1, U12.14 (SMBCLK/CFG_SEL0)
unnamed: R35.1, U12.13 (SMBDATA/NON_REM1)
unnamed: R37.1, U12.17 (SUSP_IND/LOCAL_PWR/NON_REM0)
unnamed: R100.2, R102.1, U12.16 (VBUS_DET)
unnamed: C28.2, U12.22 (XTALIN/CLKIN), Y3.3
unnamed: C33.2, U12.21 (XTALOUT/CLKIN_EN), Y3.1
USB_RP2040_N: U12.2 (USBDM_DN1/PRT_DIS_M1); also elsewhere on the board
USB_RP2040_P: U12.3 (USBDP_DN1/PRT_DIS_P1); also elsewhere on the board
VBUS: C12.1, C18.1, C26.1, C29.2, J5.A4 (VBUS[4]), J5.A9 (VBUS), J5.B4 (VBUS), J5.B9 (VBUS), R74.1, R93.1, R100.1, U5.1 (EN), U5.4 (VIN), U9.4 (VIN), U10.4 (VIN), U11.2 (IN), U11.3 (IN)
VBUS_EXT: C68.1, C69.1, J3.A4 (VBUS[4]), J3.A9 (VBUS), J3.B4 (VBUS), J3.B9 (VBUS), R31.1, R94.1, U11.8 (OUT2)

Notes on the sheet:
USB Hub
1.8V
Power Supplies
3.3V
CRT Power
1.0V
Upstream USB (to PC)
Downstream USB (to tracker)

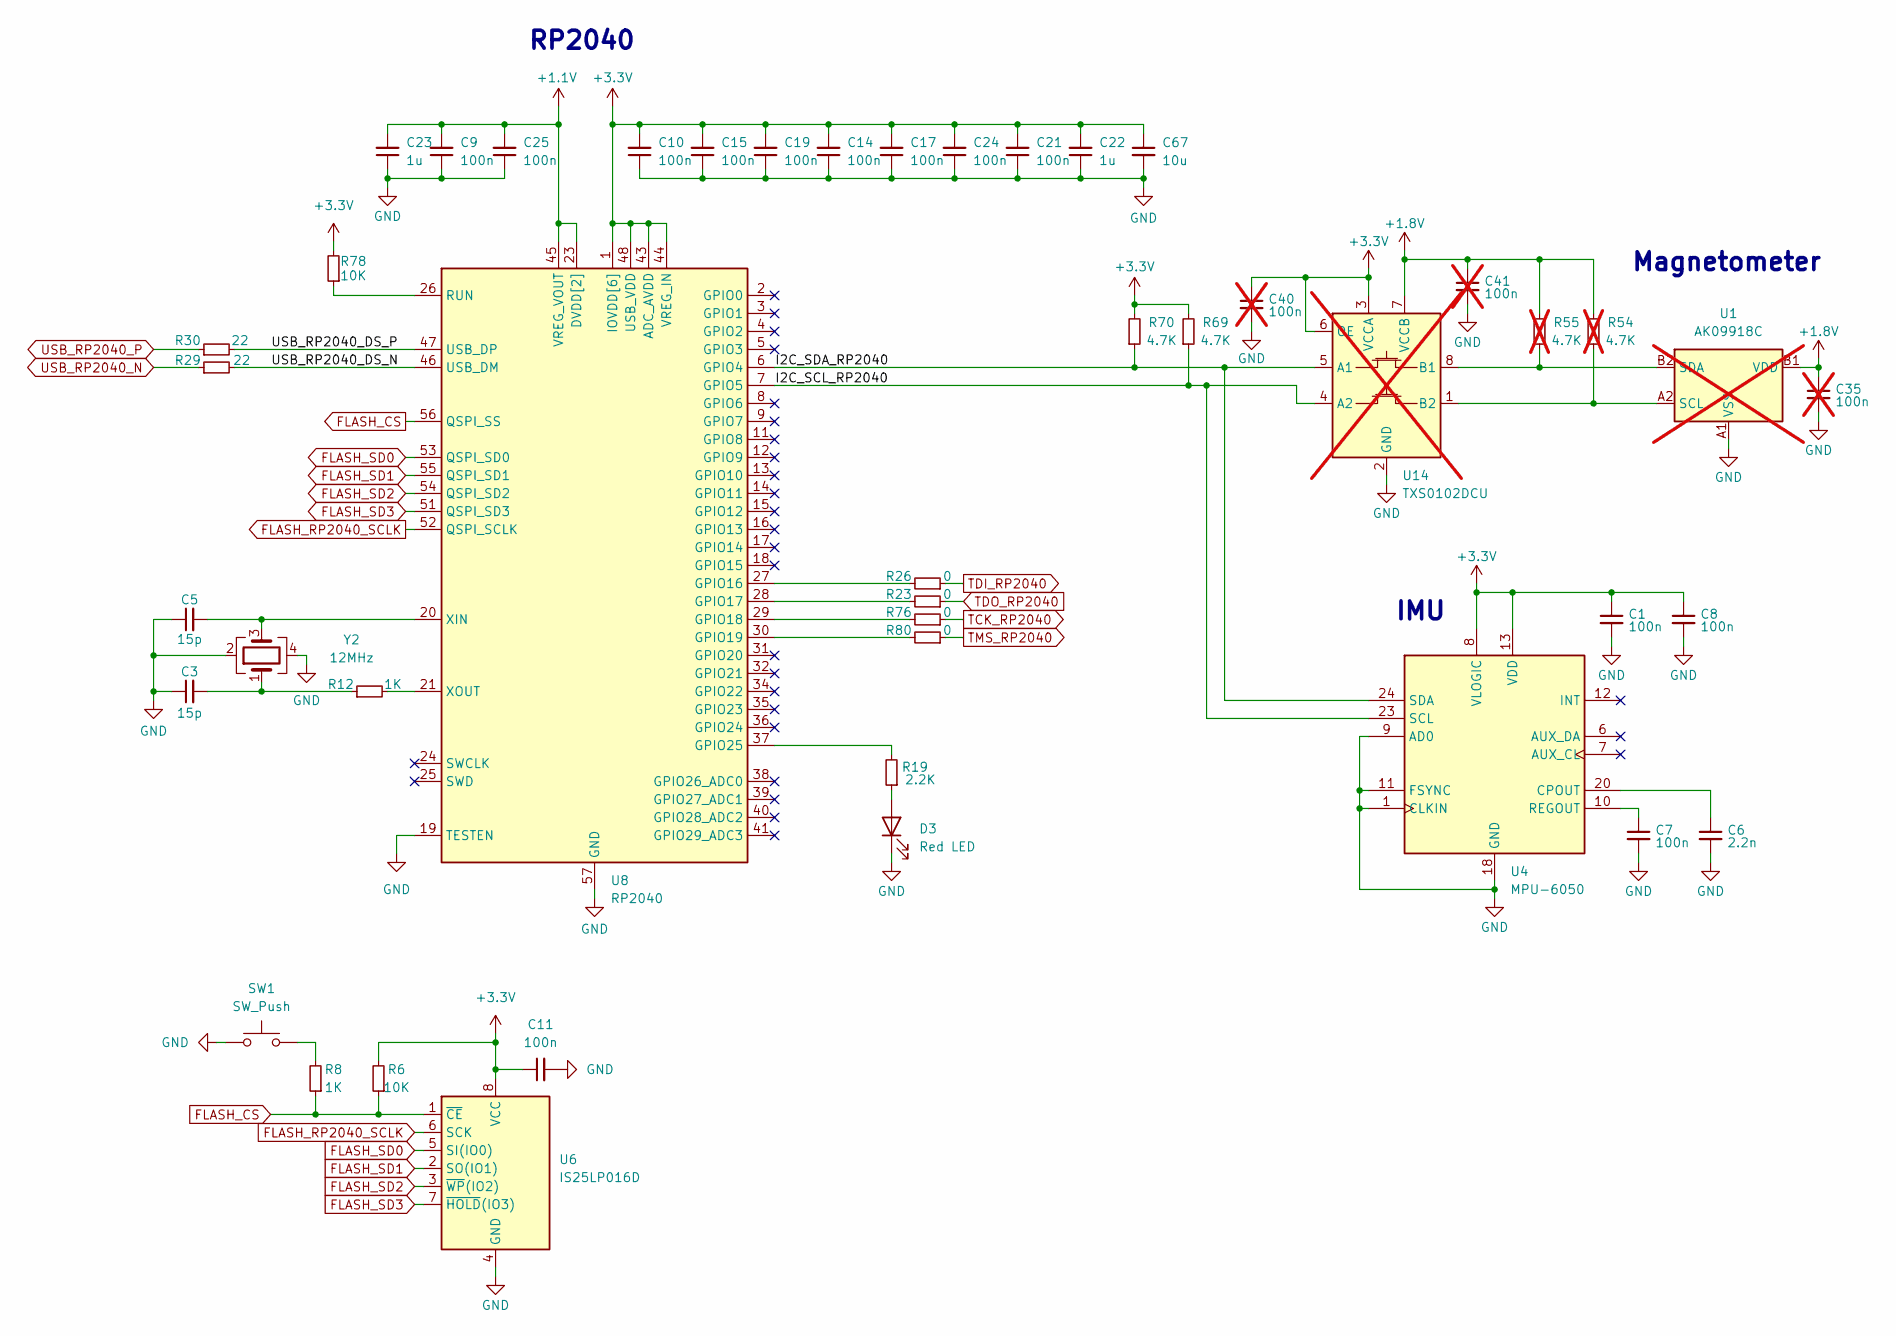
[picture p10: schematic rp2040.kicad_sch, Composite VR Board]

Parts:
C1, C7, C8, C9, C10, C11, C14, C15, C17, C19, C21, C24, C25: 100n; C_0402; Rating 16V; Tolerance 10%; Mfg PN CL05B104KO5NNNC; JLCPCB C1525
C3, C5: 15p; C_0402; Rating 50V; Tolerance 5%; Mfg PN 0402CG150J500NT; JLCPCB C1548
C6: 2.2n; C_0402; Rating 50V; Tolerance 10%; Mfg PN 0402B222K500NT; JLCPCB C1531
C22, C23: 1u; C_0402; Rating 25V; Tolerance 10%; Mfg PN CL05A105KA5NQNC; JLCPCB C52923
C35, C40, C41: 100n; C_0402; Rating 16V; Tolerance 10%; Mfg PN CL05B104KO5NNNC; JLCPCB C1525; not fitted
C67: 10u; C_0603; Rating 10V; Tolerance 10%; Mfg PN CL10A106KP8NNNC; JLCPCB C19702
D3: Red LED; LED_0603_1608Metric; Mfg PN KT-0603R; JLCPCB C2286
R6, R78: 10K; R_0402; Rating 62.5mW; Tolerance 1%; Mfg PN 0402WGF1002TCE; JLCPCB C25744
R8, R12: 1K; R_0402; Rating 62.5mW; Tolerance 1%; Mfg PN 0402WGF1001TCE; JLCPCB C11702
R19: 2.2K; R_0402; Rating 62.5mW; Tolerance 1%; Mfg PN 0402WGF2201TCE; JLCPCB C25879
R23, R26, R76, R80: 0; R_0402; Rating 62.5mW; Tolerance 1%; Mfg PN 0402WGF0000TCE; JLCPCB C17168
R29, R30: 22; R_0402; Rating 62.5mW; Tolerance 1%; Mfg PN 0402WGF220JTCE; JLCPCB C25092
R54, R55: 4.7K; R_0402; Rating 62.5mW; Tolerance 1%; Mfg PN 0402WGF4701TCE; JLCPCB C25900; not fitted
R69, R70: 4.7K; R_0402; Rating 62.5mW; Tolerance 1%; Mfg PN 0402WGF4701TCE; JLCPCB C25900
SW1: SW_Push; SW_SPST_TS-1088-xR025; Mfg PN TS-1088-AR02016; JLCPCB C720477
U1: AK09918C; WLP-4_0.83x0.83mm_P0.4mm; Mfg PN AK09918C; JLCPCB C2655004; not fitted
U4: MPU-6050; InvenSense_QFN-24_4x4mm_P0.5mm; Mfg PN MPU-6050; JLCPCB C24112
U6: IS25LP016D; SO-8_3.9x4.9mm_P1.27mm; Mfg PN IS25LP016D-JNLE-TR; JLCPCB C2653501
U8: RP2040; QFN-56-1EP_7x7mm_P0.4mm_EP3.2x3.2mm; Mfg PN RP2040; JLCPCB C2040
U14: TXS0102DCU; VSSOP-8_2.3x2mm_P0.5mm; Mfg PN TXS0102DCUR; JLCPCB C53434; not fitted
Y2: 12MHz; Crystal_SMD_3225-4Pin_3.2x2.5mm; Mfg PN 7U12000E09UCG; JLCPCB C524716

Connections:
+1.1V: C9.2, C23.2, C25.2, U8.23 (DVDD[2]), U8.45 (VREG_VOUT), U8.50 (DVDD)
+1.8V: C35.1, C41.1, R54.2, R55.2, U1.B1 (VDD), U14.7 (VCCB); also elsewhere on the board
+3.3V: C1.1, C8.1, C10.2, C11.1, C14.2, C15.2, C17.2, C19.2, C21.2, C22.2, C24.2, C40.1, C67.1, R6.2, R69.2, R70.2, R78.2, U4.8 (VLOGIC), U4.13 (VDD), U6.8 (VCC), U8.1 (IOVDD[6]), U8.10 (IOVDD), U8.22 (IOVDD), U8.33 (IOVDD), U8.42 (IOVDD), U8.43 (ADC_AVDD), U8.44 (VREG_IN), U8.48 (USB_VDD), U8.49 (IOVDD), U14.3 (VCCA), U14.6 (OE); also elsewhere on the board
/RP2040/IMU/I2C_SCL_RP2040: R69.1, U4.23 (SCL), U8.7 (GPIO5), U14.4 (A2)
/RP2040/IMU/I2C_SDA_RP2040: R70.1, U4.24 (SDA), U8.6 (GPIO4), U14.5 (A1)
/RP2040/IMU/USB_RP2040_DS_N: R29.2, U8.46 (USB_DM)
/RP2040/IMU/USB_RP2040_DS_P: R30.2, U8.47 (USB_DP)
FLASH_CS: R6.1, R8.1, U6.1 (~CE), U8.56 (QSPI_SS)
FLASH_RP2040_SCLK: U6.6 (SCK), U8.52 (QSPI_SCLK)
FLASH_SD0: U6.5 (SI(IO0)), U8.53 (QSPI_SD0)
FLASH_SD1: U6.2 (SO(IO1)), U8.55 (QSPI_SD1)
FLASH_SD2: U6.3 (~WP(IO2)), U8.54 (QSPI_SD2)
FLASH_SD3: U6.7 (~HOLD(IO3)), U8.51 (QSPI_SD3)
GND: C1.2, C3.1, C5.1, C6.2, C7.2, C8.2, C9.1, C10.1, C11.2, C14.1, C15.1, C17.1, C19.1, C21.1, C22.1, C23.1, C24.1, C25.1, C35.2, C40.2, C41.2, C67.2, D3.1 (K), SW1.1, U1.A1 (VSS), U4.1 (CLKIN), U4.9 (AD0), U4.11 (FSYNC), U4.18 (GND), U6.4 (GND), U8.19 (TESTEN), U8.57 (GND), U14.2 (GND), Y2.2, Y2.4; also elsewhere on the board
unnamed: C3.2, R12.1, Y2.1
unnamed: D3.2 (A), R19.1
unnamed: R8.2, SW1.2
unnamed: R54.1, U1.A2 (SCL), U14.1 (B2)
unnamed: R55.1, U1.B2 (SDA), U14.8 (B1)
unnamed: C6.1, U4.20 (CPOUT)
unnamed: C7.1, U4.10 (REGOUT)
unnamed: R26.2, U8.27 (GPIO16)
unnamed: R23.2, U8.28 (GPIO17)
unnamed: R76.2, U8.29 (GPIO18)
unnamed: R80.2, U8.30 (GPIO19)
unnamed: R19.2, U8.37 (GPIO25)
unnamed: R78.1, U8.26 (RUN)
unnamed: C5.2, U8.20 (XIN), Y2.3
unnamed: R12.2, U8.21 (XOUT)
TCK_RP2040: R76.1; also elsewhere on the board
TDI_RP2040: R26.1; also elsewhere on the board
TDO_RP2040: R23.1; also elsewhere on the board
TMS_RP2040: R80.1; also elsewhere on the board
USB_RP2040_N: R29.1; also elsewhere on the board
USB_RP2040_P: R30.1; also elsewhere on the board

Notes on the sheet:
IMU
Magnetometer
RP2040

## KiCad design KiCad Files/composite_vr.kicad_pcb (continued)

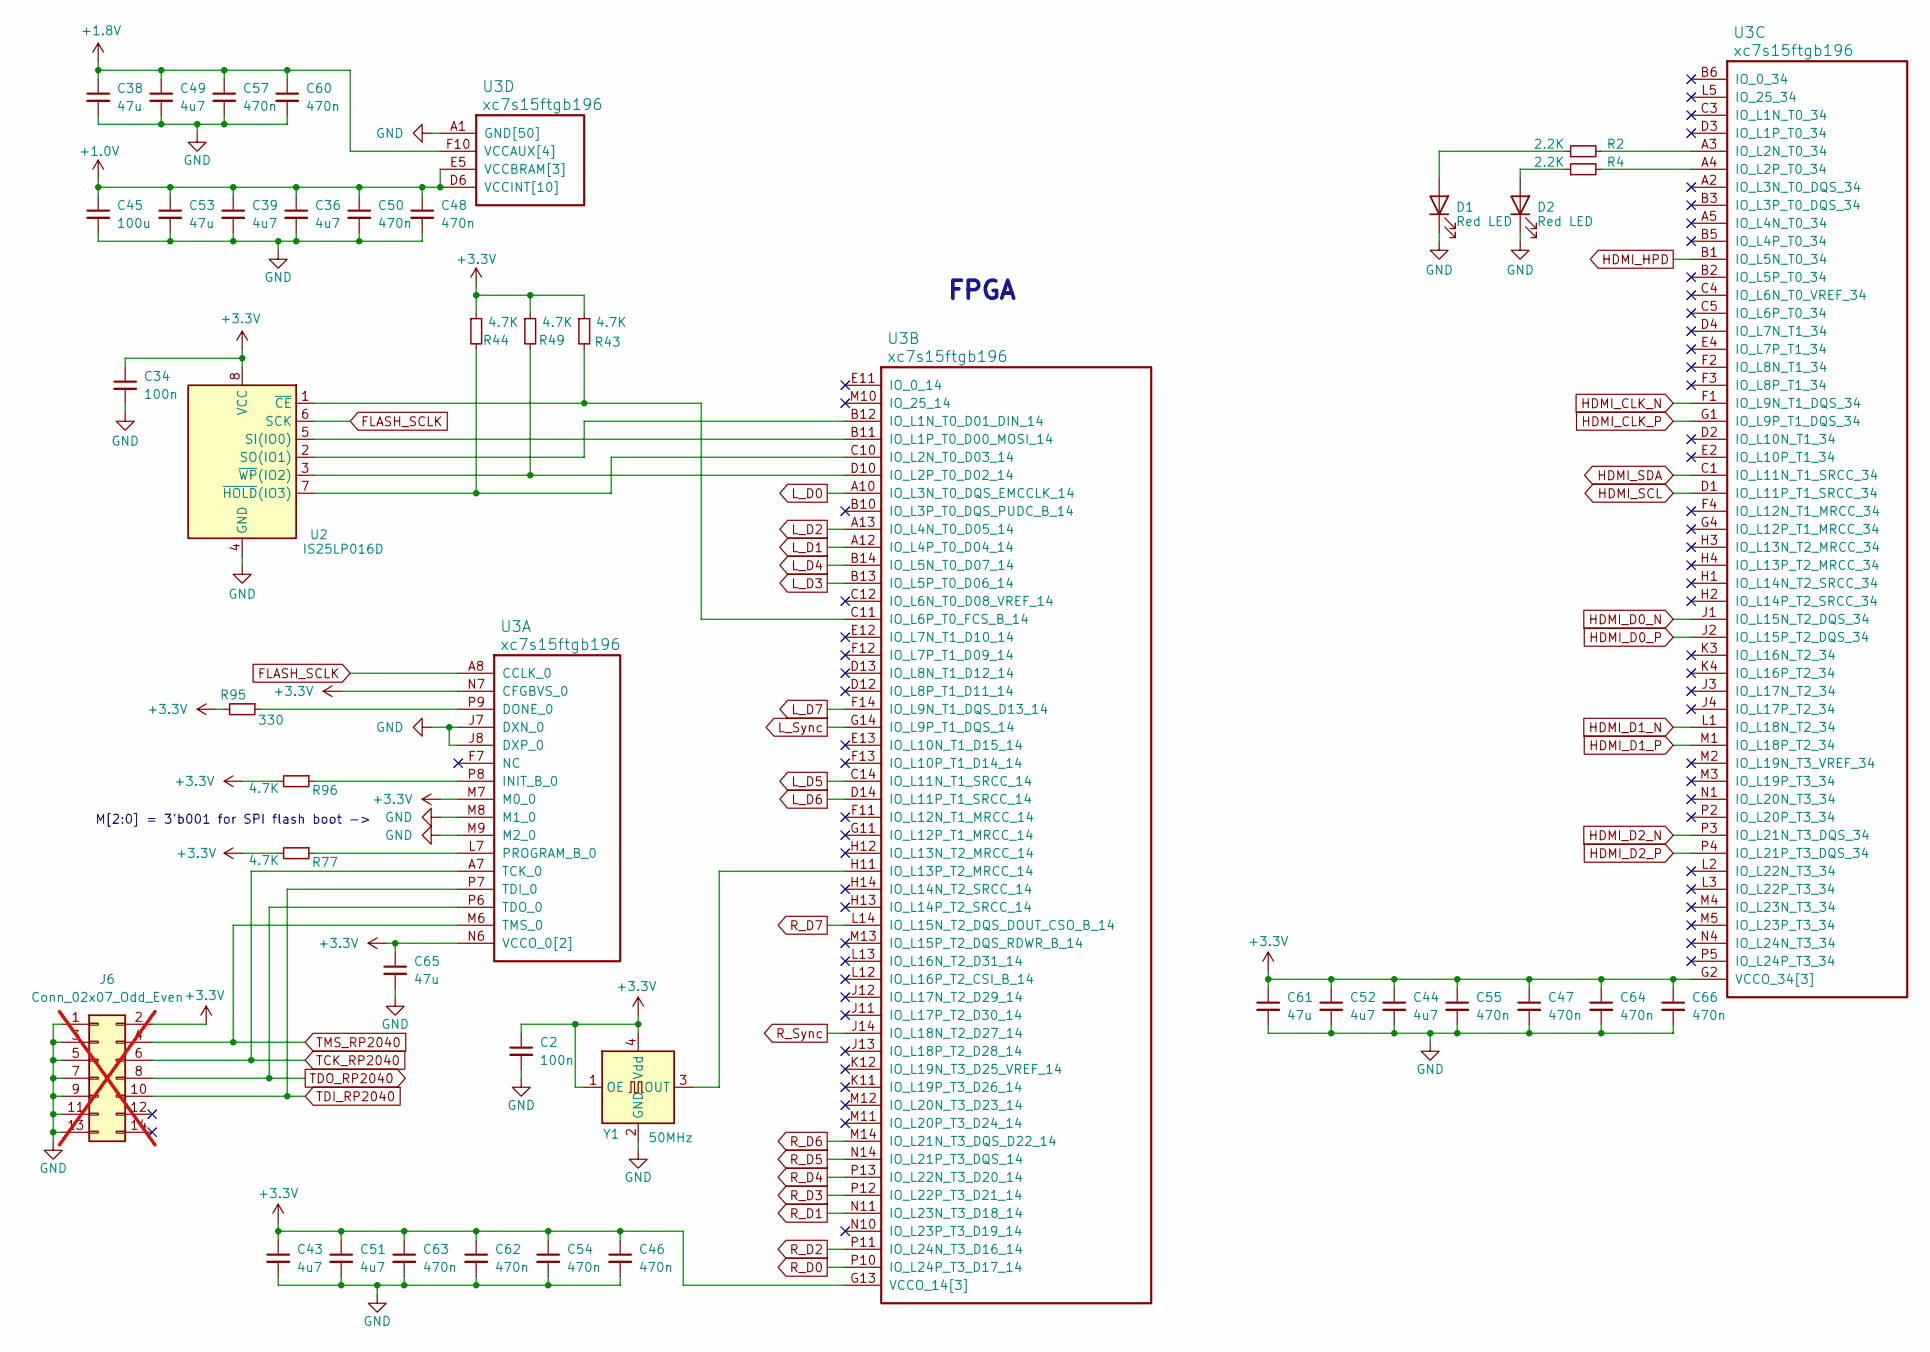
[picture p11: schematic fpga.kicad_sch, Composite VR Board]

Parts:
C2, C34: 100n; C_0402; Rating 16V; Tolerance 10%; Mfg PN CL05B104KO5NNNC; JLCPCB C1525
C36, C39, C43, C44, C49, C51, C52: 4u7; C_0402; Rating 10V; Tolerance 20%; Mfg PN CL05A475MP5NRNC; JLCPCB C23733
C38, C53, C61, C65: 47u; C_0805; Rating 6.3V; Tolerance 20%; Mfg PN CL21A476MQYNNNE; JLCPCB C16780
C45: 100u; C_1206; Rating 6.3V; Tolerance 20%; Mfg PN CL31A107MQHNNNE; JLCPCB C15008
C46, C47, C48, C50, C54, C55, C57, C60, C62, C63, C64, C66: 470n; C_0402; Rating 10V; Tolerance 10%; Mfg PN CL05A474KP5NNNC; JLCPCB C47339
D1, D2: Red LED; LED_0603_1608Metric; Mfg PN KT-0603R; JLCPCB C2286
J6: Conn_02x07_Odd_Even; PinHeader_2x07_P2.00mm_Vertical_SMD; not fitted
R2, R4: 2.2K; R_0402; Rating 62.5mW; Tolerance 1%; Mfg PN 0402WGF2201TCE; JLCPCB C25879
R43, R44, R49, R77, R96: 4.7K; R_0402; Rating 62.5mW; Tolerance 1%; Mfg PN 0402WGF4701TCE; JLCPCB C25900
R95: 330; R_0402; Rating 62.5mW; Tolerance 1%; Mfg PN 0402WGF3300TCE; JLCPCB C25104
U2: IS25LP016D; SO-8_3.9x4.9mm_P1.27mm; Mfg PN IS25LP016D-JNLE-TR; JLCPCB C2653501
U3: xc7s15ftgb196; Xilinx_FTGB196; Mfg PN XC7S15-2FTGB196I; JLCPCB C1521865
Y1: 50MHz; Oscillator_SMD_SiT_PQFN-4Pin_3.2x2.5mm; Mfg PN SiT8008BI-22-33E-50.000000; JLCPCB C26267

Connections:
+1.0V: C36.1, C39.1, C45.1, C48.1, C50.1, C53.1, U3.D6 (VCCINT[10]), U3.D8 (VCCINT[10]), U3.E5 (VCCBRAM[3]), U3.E7 (VCCINT[10]), U3.E9 (VCCINT[10]), U3.F6 (VCCINT[10]), U3.G5 (VCCBRAM[3]), U3.G9 (VCCINT[10]), U3.H6 (VCCINT[10]), U3.J5 (VCCBRAM[3]), U3.J9 (VCCINT[10]), U3.K6 (VCCINT[10]), U3.K8 (VCCINT[10]); also elsewhere on the board
+1.8V: C38.1, C49.1, C57.1, C60.1, U3.F10 (VCCAUX[4]), U3.H10 (VCCAUX[4]), U3.K10 (VCCAUX[4]), U3.L9 (VCCAUX[4]); also elsewhere on the board
+3.3V: C2.1, C34.1, C43.1, C44.1, C46.1, C47.1, C51.1, C52.1, C54.1, C55.1, C61.1, C62.1, C63.1, C64.1, C65.1, C66.1, J6.2, R43.1, R44.1, R49.1, R77.2, R95.2, R96.2, U2.8 (VCC), U3.G2 (VCCO_34[3]), U3.G13 (VCCO_14[3]), U3.K2 (VCCO_34[3]), U3.K13 (VCCO_14[3]), U3.M7 (M0_0), U3.N2 (VCCO_34[3]), U3.N6 (VCCO_0[2]), U3.N7 (CFGBVS_0), U3.N8 (VCCO_0[2]), U3.N13 (VCCO_14[3]), Y1.1 (OE), Y1.4 (Vdd); also elsewhere on the board
FLASH_SCLK: U2.6 (SCK), U3.A8 (CCLK_0)
GND: C2.2, C34.2, C36.2, C38.2, C39.2, C43.2, C44.2, C45.2, C46.2, C47.2, C48.2, C49.2, C50.2, C51.2, C52.2, C53.2, C54.2, C55.2, C57.2, C60.2, C61.2, C62.2, C63.2, C64.2, C65.2, C66.2, D1.1 (K), D2.1 (K), J6.1, J6.3, J6.5, J6.7, J6.9, J6.11, J6.13, U2.4 (GND), U3.A1 (GND[50]), U3.A6 (GND[50]), U3.A9 (GND[50]), U3.A11 (GND[50]), U3.A14 (GND[50]), U3.B4 (GND[50]), U3.B7 (GND[50]), U3.B9 (GND[50]), U3.C2 (GND[50]), U3.C6 (GND[50]), U3.C7 (GND[50]), U3.C8 (GND[50]), U3.C9 (GND[50]), U3.C13 (GND[50]), U3.D5 (GND[50]), U3.D7 (GND[50]), U3.D9 (GND[50]), U3.D11 (GND[50]), U3.E1 (GND[50]), U3.E3 (GND[50]), U3.E6 (GND[50]), U3.E8 (GND[50]), U3.E10 (GND[50]), U3.E14 (GND[50]), U3.F5 (GND[50]), U3.F9 (GND[50]), U3.G3 (GND[50]), U3.G6 (GND[50]), U3.G10 (GND[50]), U3.G12 (GND[50]), U3.H5 (GND[50]), U3.H9 (GND[50]), U3.J6 (GND[50]), U3.J7 (DXN_0), U3.J8 (DXP_0), U3.J10 (GND[50]), U3.K1 (GND[50]), U3.K5 (GND[50]), U3.K7 (GND[50]), U3.K9 (GND[50]), U3.K14 (GND[50]), U3.L4 (GND[50]), U3.L6 (GND[50]), U3.L8 (GND[50]), U3.L10 (GND[50]), U3.L11 (GND[50]), U3.M8 (M1_0), U3.M9 (M2_0), U3.N3 (GND[50]), U3.N5 (GND[50]), U3.N9 (GND[50]), U3.N12 (GND[50]), U3.P1 (GND[50]), U3.P14 (GND[50]), Y1.2 (GND); also elsewhere on the board
HDMI_CLK_N: U3.F1 (IO_L9N_T1_DQS_34); also elsewhere on the board
HDMI_CLK_P: U3.G1 (IO_L9P_T1_DQS_34); also elsewhere on the board
HDMI_D0_N: U3.J1 (IO_L15N_T2_DQS_34); also elsewhere on the board
HDMI_D0_P: U3.J2 (IO_L15P_T2_DQS_34); also elsewhere on the board
HDMI_D1_N: U3.L1 (IO_L18N_T2_34); also elsewhere on the board
HDMI_D1_P: U3.M1 (IO_L18P_T2_34); also elsewhere on the board
HDMI_D2_N: U3.P3 (IO_L21N_T3_DQS_34); also elsewhere on the board
HDMI_D2_P: U3.P4 (IO_L21P_T3_DQS_34); also elsewhere on the board
HDMI_HPD: U3.B1 (IO_L5N_T0_34); also elsewhere on the board
HDMI_SCL: U3.D1 (IO_L11P_T1_SRCC_34); also elsewhere on the board
HDMI_SDA: U3.C1 (IO_L11N_T1_SRCC_34); also elsewhere on the board
L_D0: U3.A10 (IO_L3N_T0_DQS_EMCCLK_14); also elsewhere on the board
L_D1: U3.A12 (IO_L4P_T0_D04_14); also elsewhere on the board
L_D2: U3.A13 (IO_L4N_T0_D05_14); also elsewhere on the board
L_D3: U3.B13 (IO_L5P_T0_D06_14); also elsewhere on the board
L_D4: U3.B14 (IO_L5N_T0_D07_14); also elsewhere on the board
L_D5: U3.C14 (IO_L11N_T1_SRCC_14); also elsewhere on the board
L_D6: U3.D14 (IO_L11P_T1_SRCC_14); also elsewhere on the board
L_D7: U3.F14 (IO_L9N_T1_DQS_D13_14); also elsewhere on the board
L_Sync: U3.G14 (IO_L9P_T1_DQS_14); also elsewhere on the board
unnamed: D1.2 (A), R2.1
unnamed: D2.2 (A), R4.1
unnamed: U2.5 (SI(IO0)), U3.B11 (IO_L1P_T0_D00_MOSI_14)
unnamed: U2.2 (SO(IO1)), U3.B12 (IO_L1N_T0_D01_DIN_14)
unnamed: R43.2, U2.1 (~CE), U3.C11 (IO_L6P_T0_FCS_B_14)
unnamed: R44.2, U2.7 (~HOLD(IO3)), U3.C10 (IO_L2N_T0_D03_14)
unnamed: R49.2, U2.3 (~WP(IO2)), U3.D10 (IO_L2P_T0_D02_14)
unnamed: R95.1, U3.P9 (DONE_0)
unnamed: R96.1, U3.P8 (INIT_B_0)
unnamed: R77.1, U3.L7 (PROGRAM_B_0)
unnamed: U3.H11 (IO_L13P_T2_MRCC_14), Y1.3 (OUT)
unnamed: R2.2, U3.A3 (IO_L2N_T0_34)
unnamed: R4.2, U3.A4 (IO_L2P_T0_34)
R_D0: U3.P10 (IO_L24P_T3_D17_14); also elsewhere on the board
R_D1: U3.N11 (IO_L23N_T3_D18_14); also elsewhere on the board
R_D2: U3.P11 (IO_L24N_T3_D16_14); also elsewhere on the board
R_D3: U3.P12 (IO_L22P_T3_D21_14); also elsewhere on the board
R_D4: U3.P13 (IO_L22N_T3_D20_14); also elsewhere on the board
R_D5: U3.N14 (IO_L21P_T3_DQS_14); also elsewhere on the board
R_D6: U3.M14 (IO_L21N_T3_DQS_D22_14); also elsewhere on the board
R_D7: U3.L14 (IO_L15N_T2_DQS_DOUT_CSO_B_14); also elsewhere on the board
R_Sync: U3.J14 (IO_L18N_T2_D27_14); also elsewhere on the board
TCK_RP2040: J6.6, U3.A7 (TCK_0); also elsewhere on the board
TDI_RP2040: J6.10, U3.P7 (TDI_0); also elsewhere on the board
TDO_RP2040: J6.8, U3.P6 (TDO_0); also elsewhere on the board
TMS_RP2040: J6.4, U3.M6 (TMS_0); also elsewhere on the board

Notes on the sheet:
FPGA
M[2:0] = 3'b001 for SPI flash boot ->

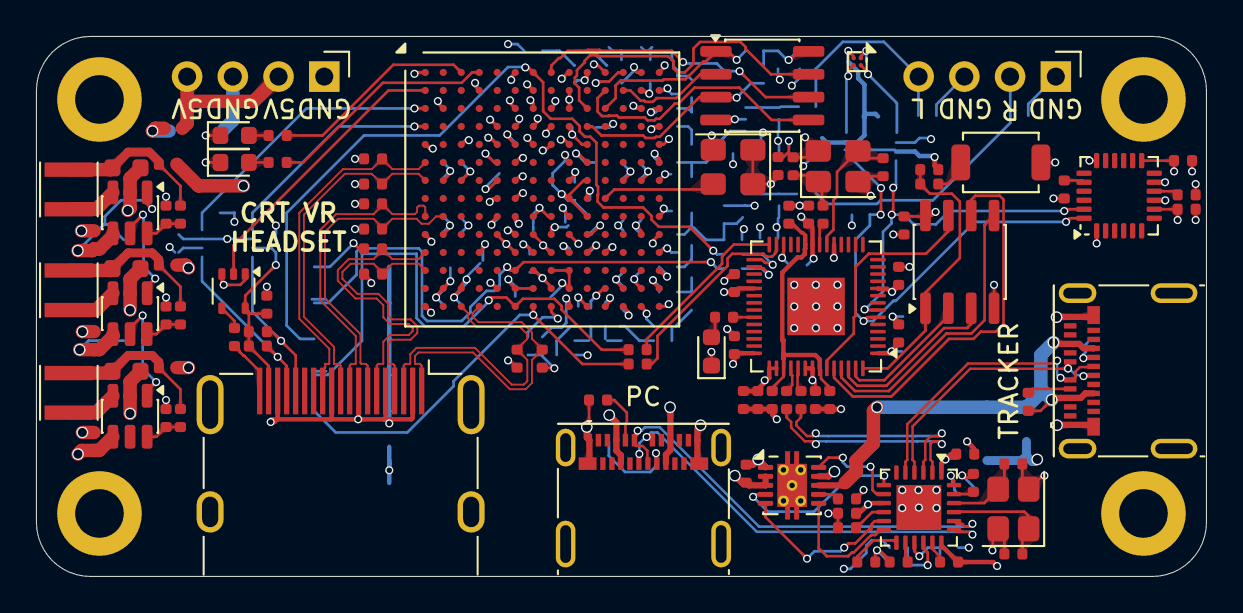
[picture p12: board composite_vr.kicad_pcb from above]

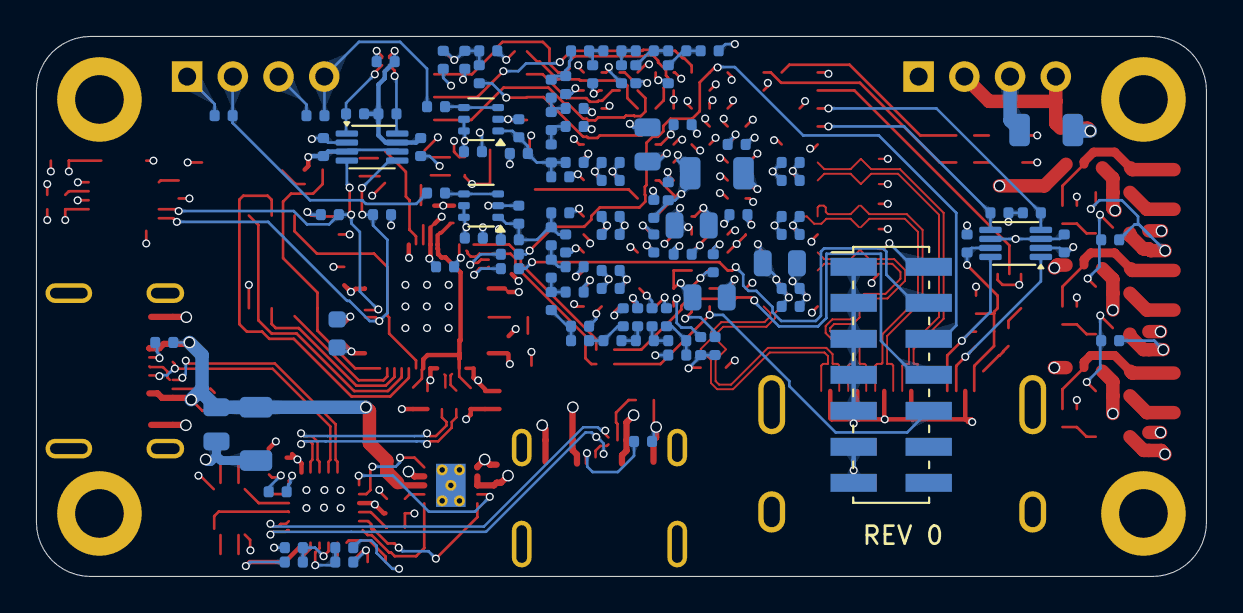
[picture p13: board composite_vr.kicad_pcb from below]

Board: 4 copper layers, 65.0 x 30.0 mm, 208 parts (107 on the bottom side), 142 nets.

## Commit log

2026-06-29 Enhance README with detailed project description
    Expanded the README to include detailed information about the controller board's functionality, components, and usage with Vive Tracker.
2026-06-29 Update README with Relativty reference
    Added reference to Relativty for IMU tracking data transmission.
